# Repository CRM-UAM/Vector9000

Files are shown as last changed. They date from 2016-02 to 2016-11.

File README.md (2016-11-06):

Vector-9000, a fast line follower robot
===============

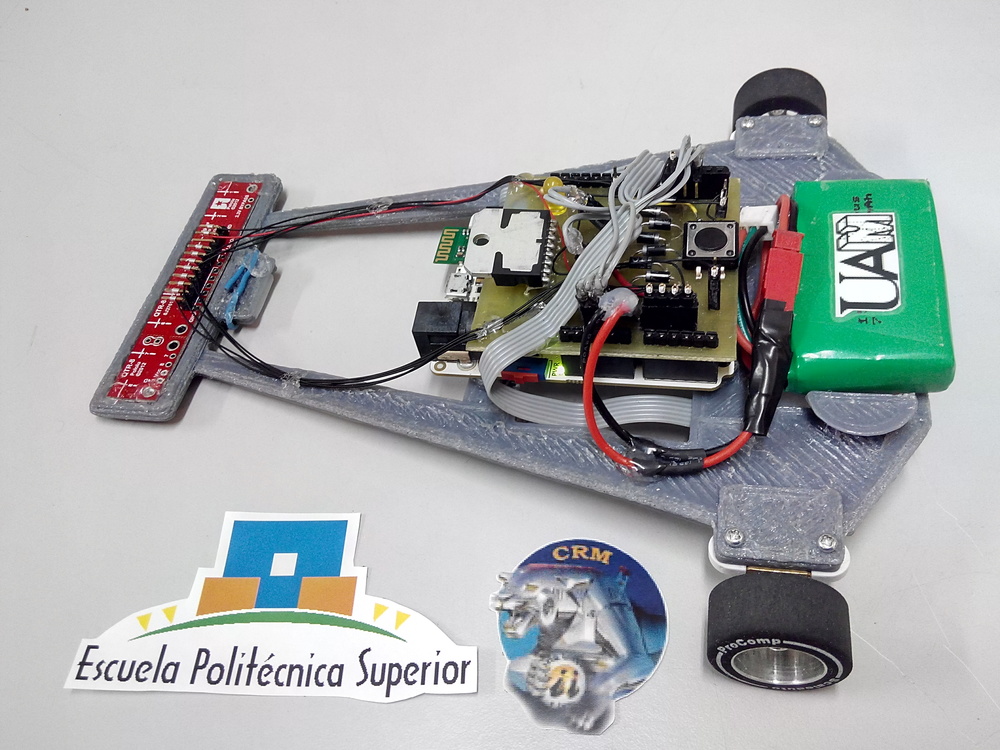
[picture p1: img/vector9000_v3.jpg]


Description
--------
By Carlosgs and Víctor Uceda.<br />
<br />
This robot was designed and built two weeks ahead the Cosmobot 2013 competition (http://www.roboticspot.com/cosmobot/).<br />

Video: <a href="http://www.youtube.com/watch?v=wgSMBDEtGO0" target="_blank" rel="nofollow">youtube.com/watch?v=wgSMBDEtGO0</a><br />

Tech specs:<br />

 - Arduino Leonardo with CRM Shield + MUX + lots of wire-wrapping<br />
 - Pololu QTR-8A (RC) and CNY-70 line sensor boards<br />
 - 7.4V Li-Po battery<br />
 - LDR sensor array (x4) as an experiment to determine the robot's orientation

Files
--------

 [ SoporteLDR.stl](3D_design/SoporteLDR.stl)  


 [ TercerApoyo.stl](3D_design/TercerApoyo.stl)  


 [ NuevaCover.stl](3D_design/NuevaCover.stl)  


 [ Chasis.stl](3D_design/Chasis.stl)  


 [ CubiertaPololu.stl](3D_design/CubiertaPololu.stl)  

 Original design as of 2013:
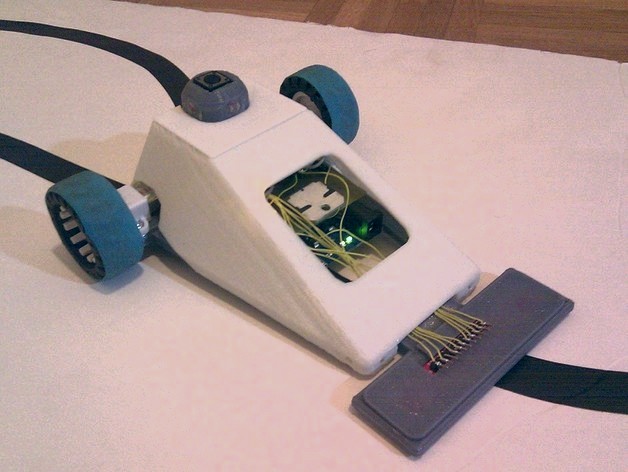
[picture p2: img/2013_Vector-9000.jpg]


License: CC-BY-SA 4.0 international


 [ TercerApoyo.scad](3D_design/TercerApoyo.scad)  


 [ LineSensorV2_new.scad](3D_design/LineSensorV2_new.scad)  


 [ CubiertaPololu.scad](3D_design/CubiertaPololu.scad)  


 [ CubiertaCarcasa.scad](3D_design/CubiertaCarcasa.scad)  


 [ Chasis.scad](3D_design/Chasis.scad)  


 [ CubiertaCarcasa.stl](3D_design/CubiertaCarcasa.stl)  


 [ SoporteLDR.scad](3D_design/SoporteLDR.scad)  

Pictures
--------
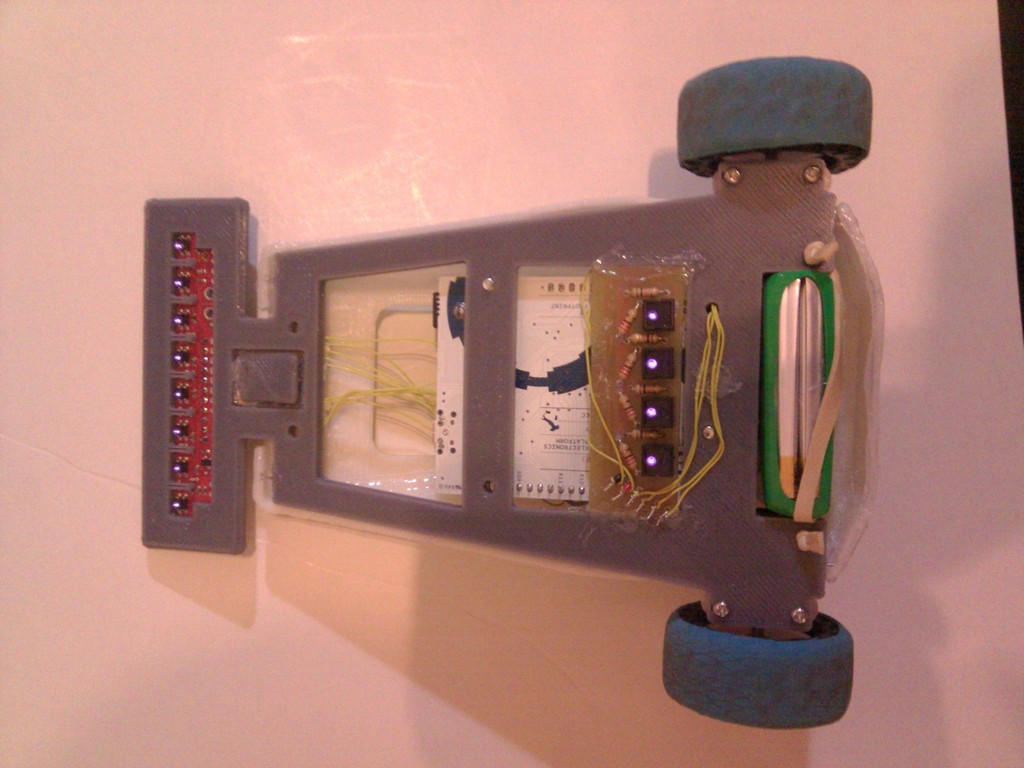
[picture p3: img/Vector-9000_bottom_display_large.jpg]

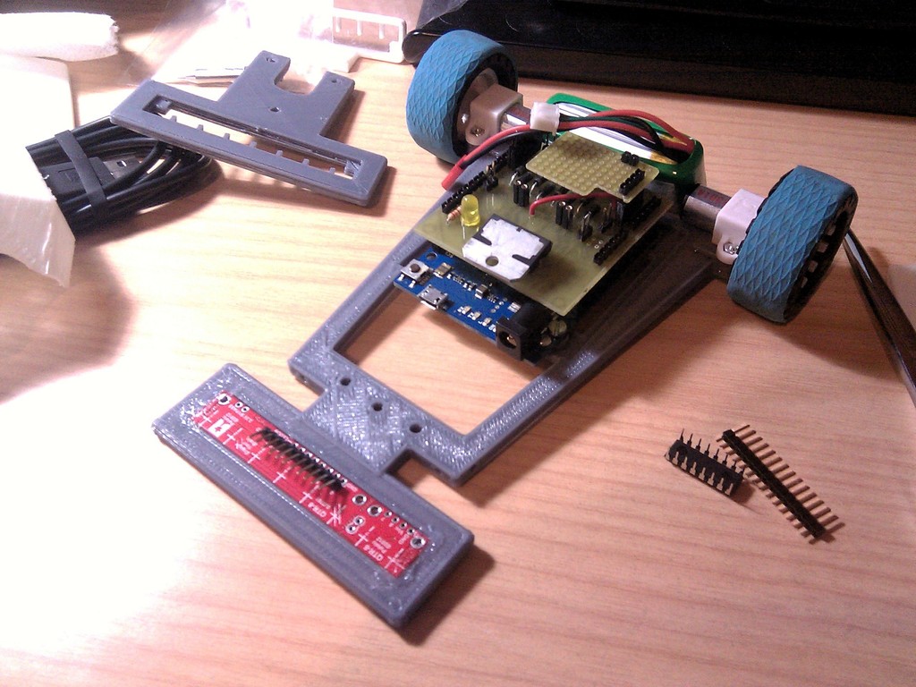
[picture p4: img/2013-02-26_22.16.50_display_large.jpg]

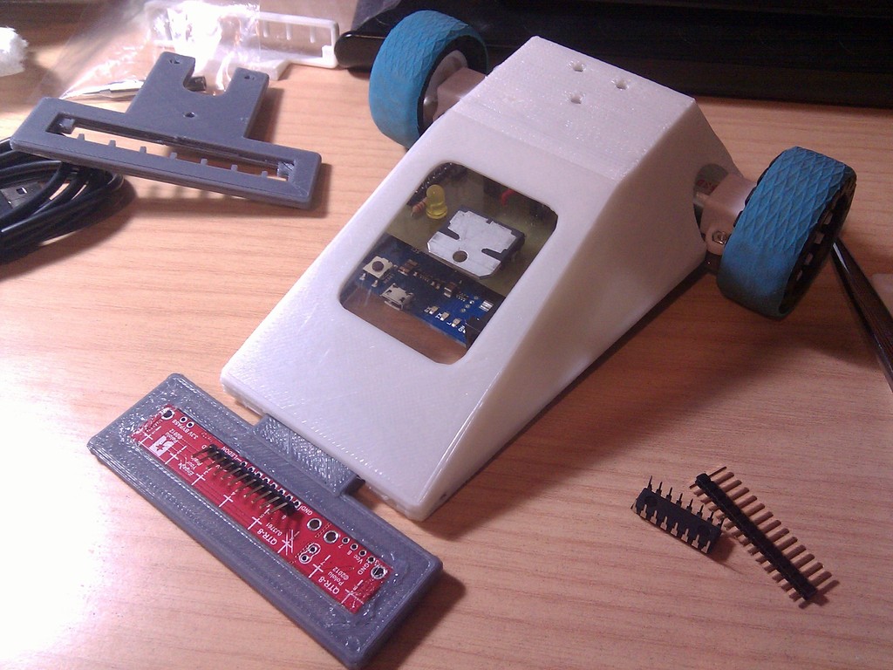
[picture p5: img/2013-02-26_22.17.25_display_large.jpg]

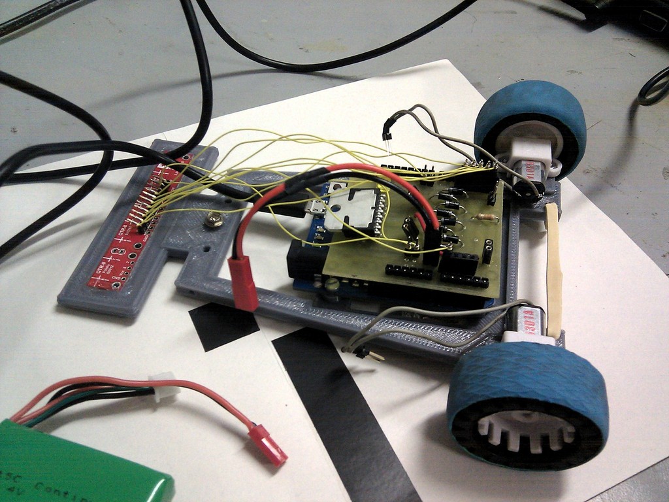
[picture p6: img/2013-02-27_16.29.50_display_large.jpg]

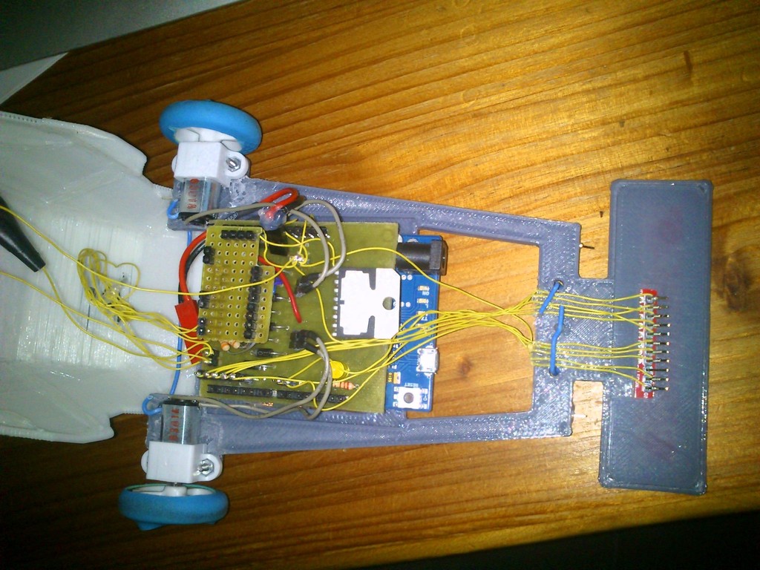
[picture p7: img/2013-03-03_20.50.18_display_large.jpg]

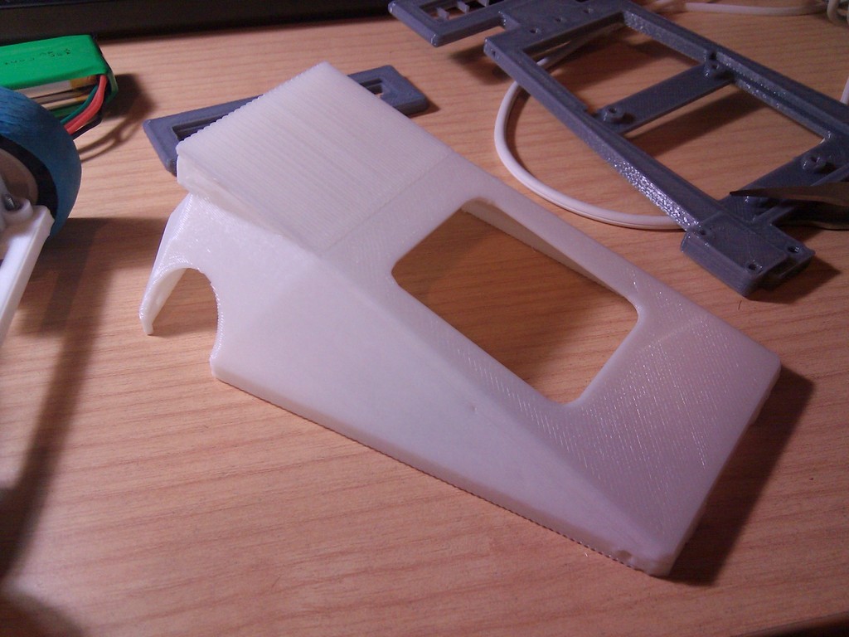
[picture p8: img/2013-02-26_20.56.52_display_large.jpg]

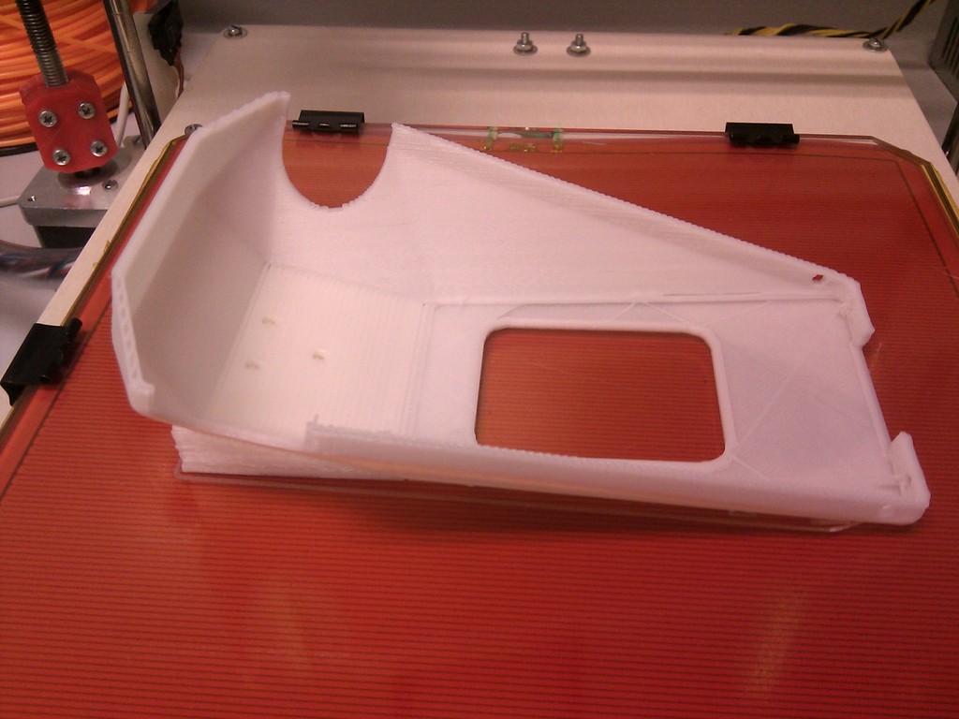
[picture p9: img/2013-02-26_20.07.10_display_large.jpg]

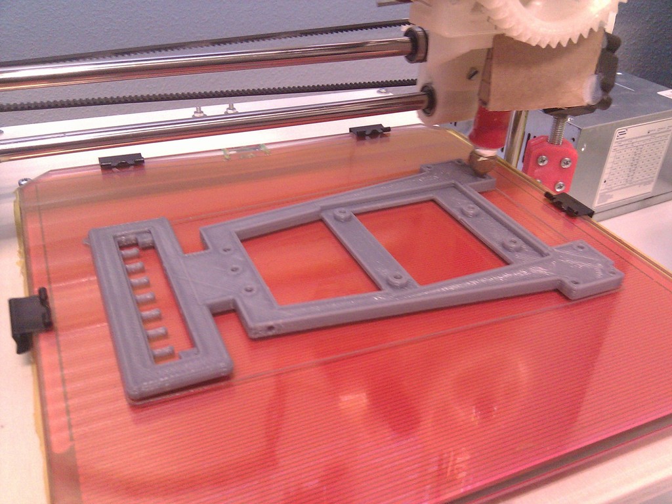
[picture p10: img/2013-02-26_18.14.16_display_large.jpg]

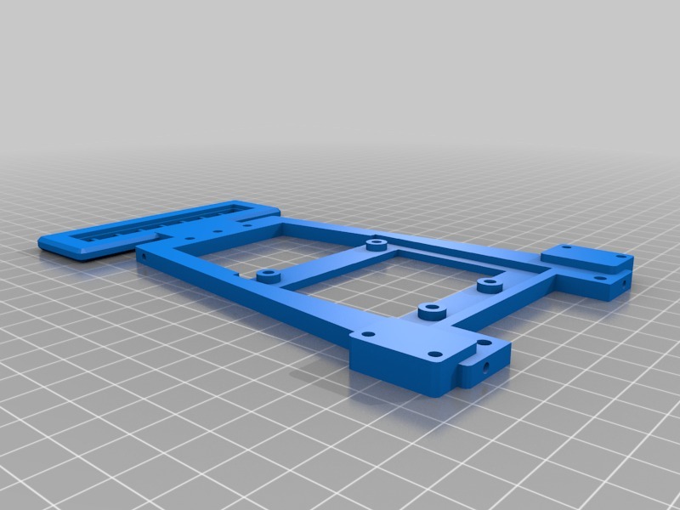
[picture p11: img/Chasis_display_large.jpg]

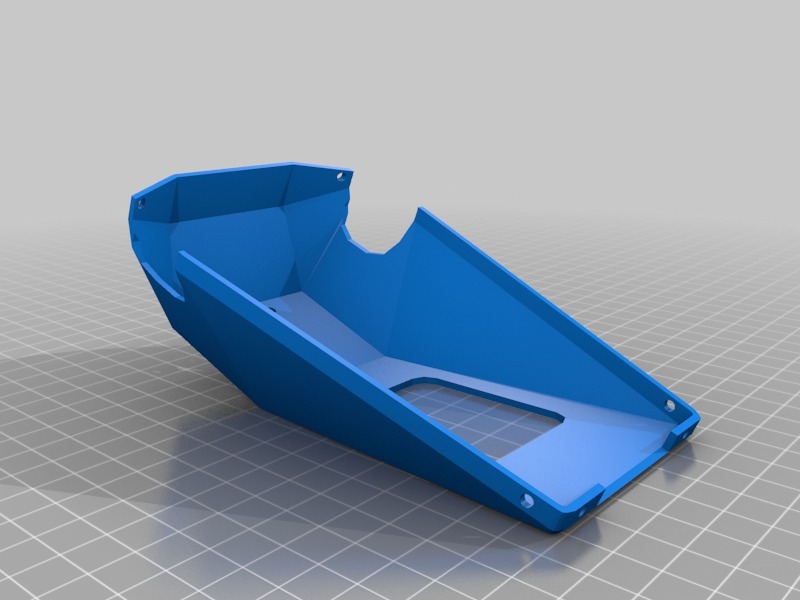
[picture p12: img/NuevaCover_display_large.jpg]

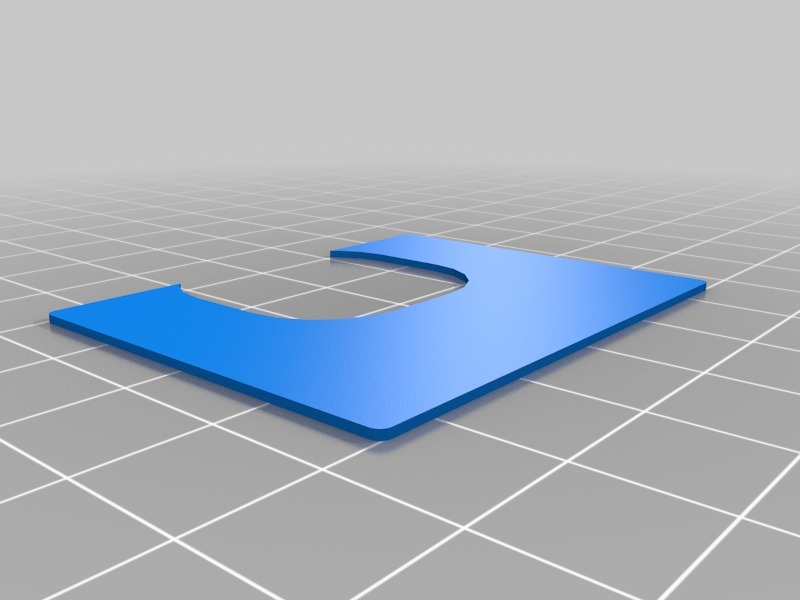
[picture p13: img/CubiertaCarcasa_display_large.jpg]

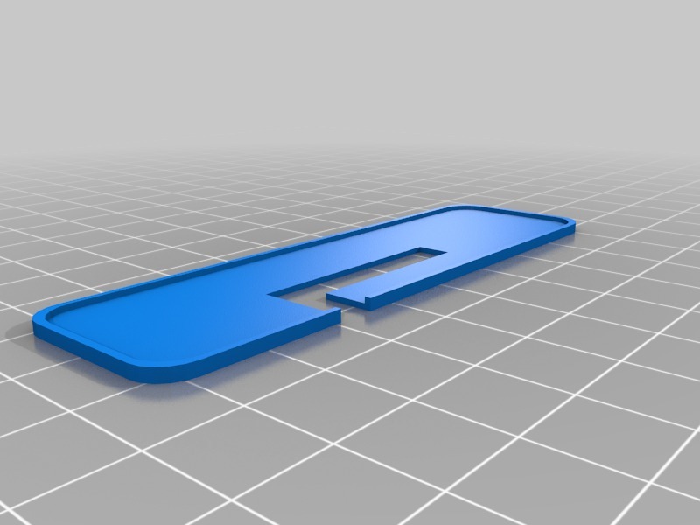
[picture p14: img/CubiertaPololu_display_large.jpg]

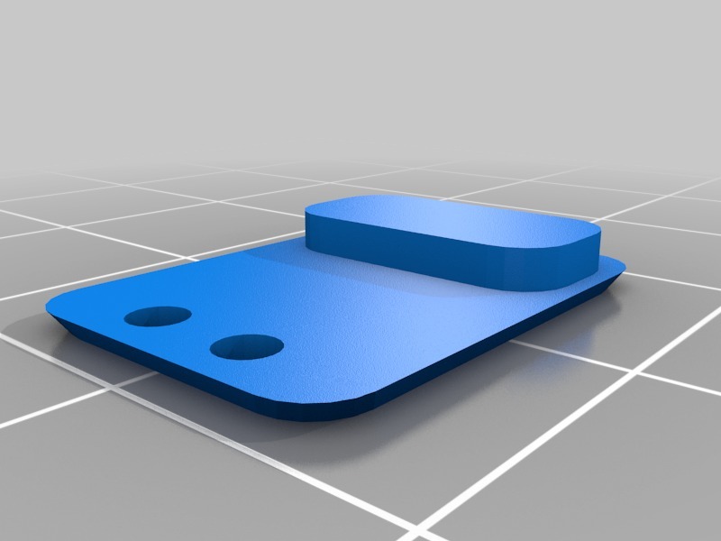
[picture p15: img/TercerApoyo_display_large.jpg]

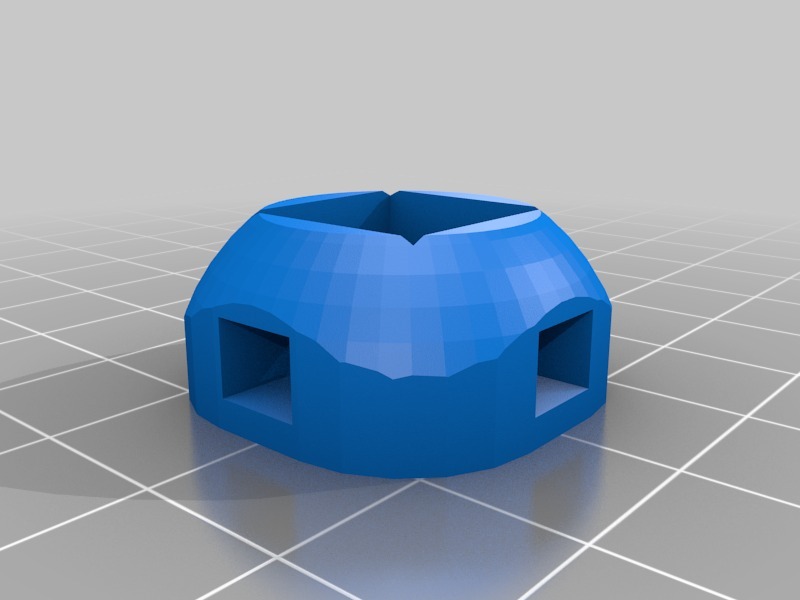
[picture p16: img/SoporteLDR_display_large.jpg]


Tags
--------
ARDUINO , CRM , PLASTIC_VALLEY , PRINTBOT , SHIELD , UAM  

License
--------
Vector-9000, a fast line follower robot by carlosgs is licensed under the Creative Commons - Attribution - Share Alike license.

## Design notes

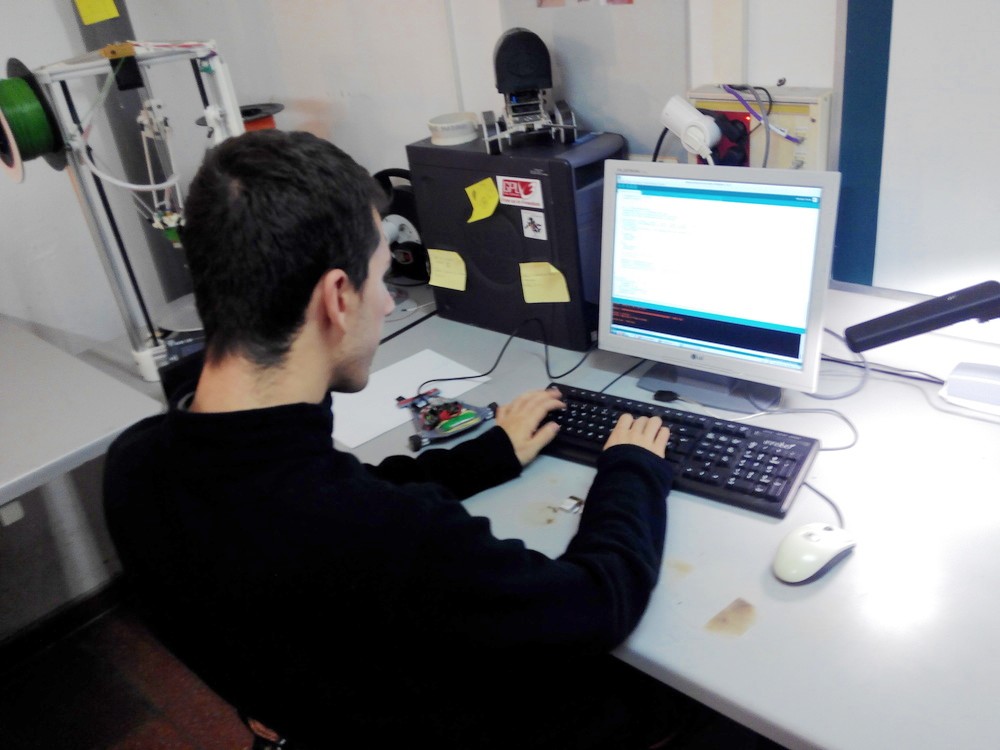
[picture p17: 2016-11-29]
img/2016-10-30_Victor_a_tope_Vector9000.jpg

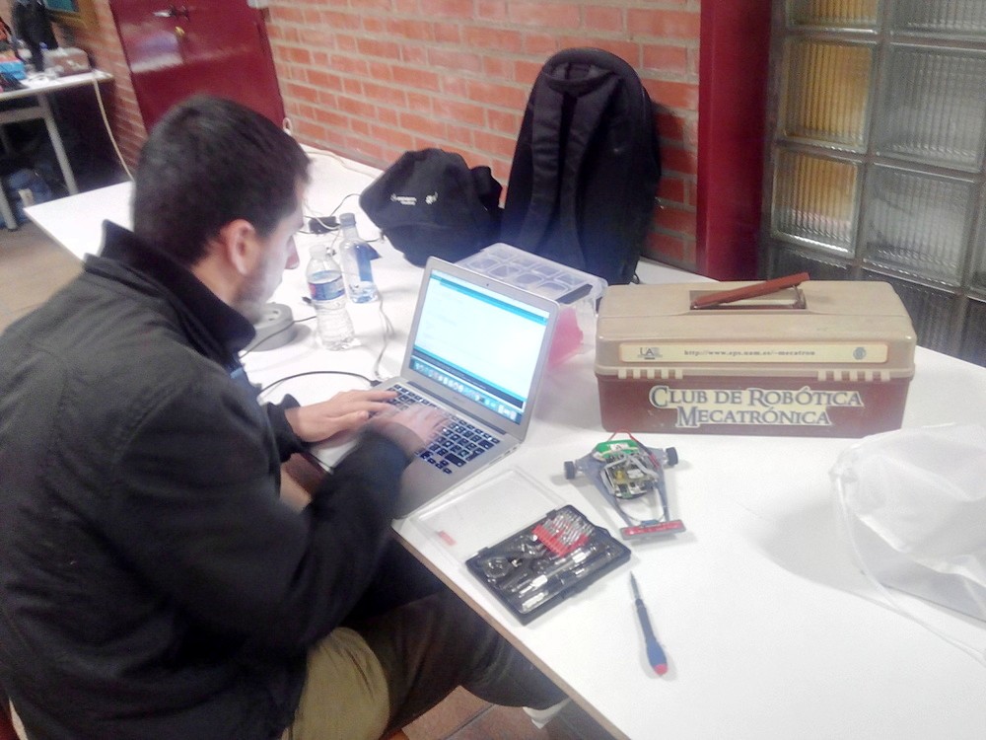
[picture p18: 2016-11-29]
img/2016-04-08 13.01.25.jpg

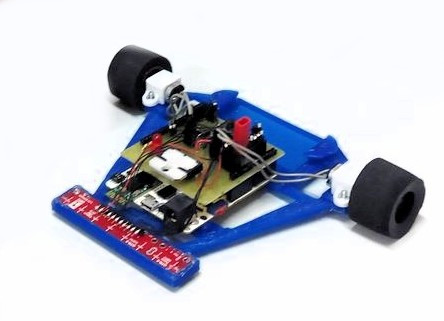
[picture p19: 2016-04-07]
img/miniVector_7apr2016_robolid.jpeg

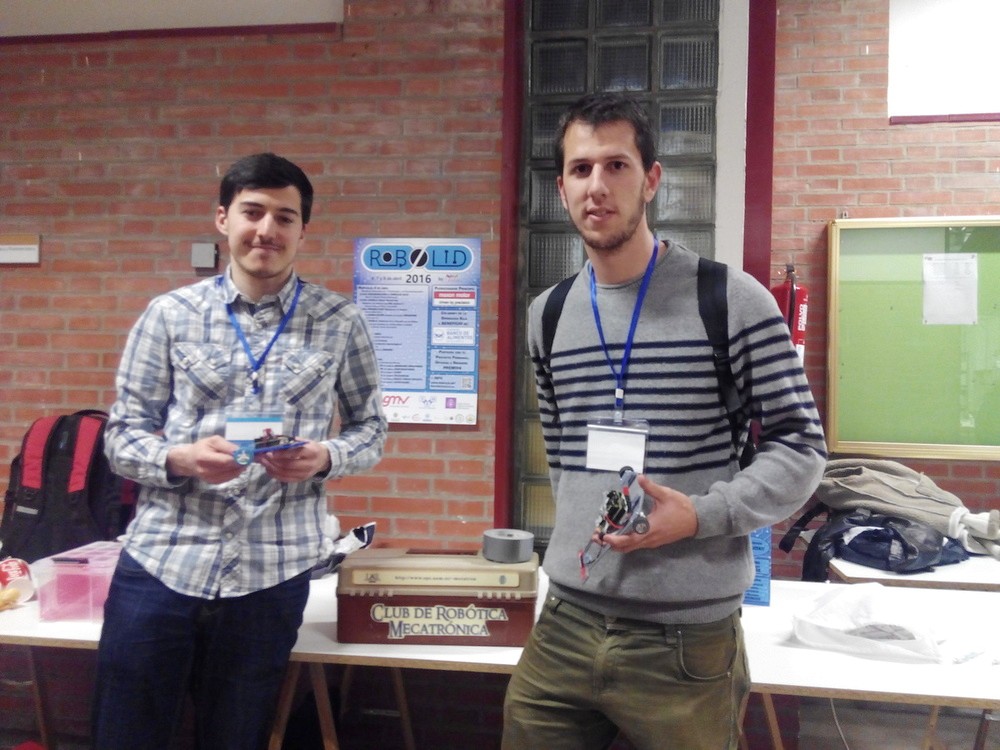
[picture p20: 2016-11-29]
img/2016-04-08 20.31.52.jpg

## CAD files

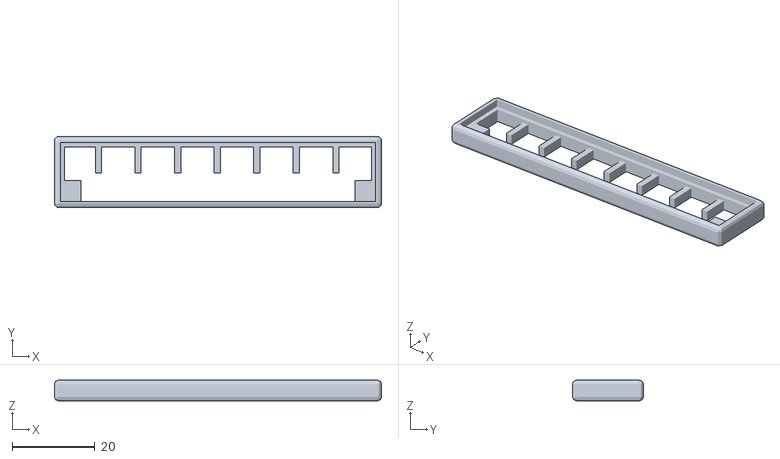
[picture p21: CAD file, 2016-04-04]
3D_design/LineSensorV2_new.stl
79.0 x 17.2 x 5.00

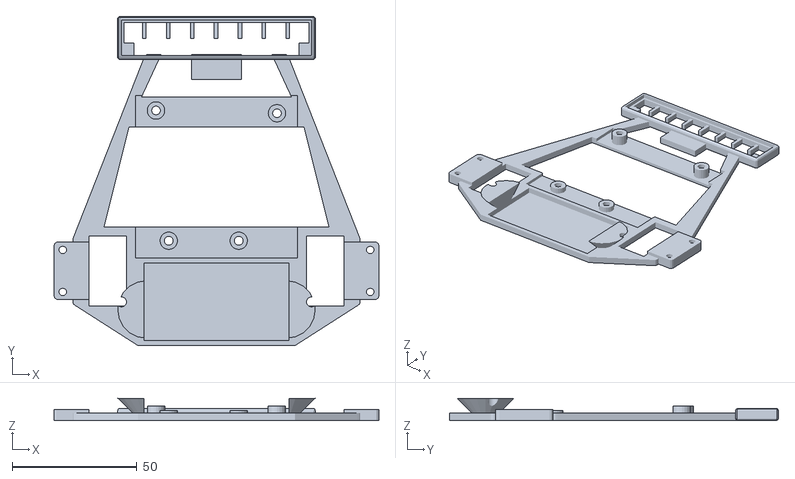
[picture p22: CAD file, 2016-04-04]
3D_design/STL/Chasis_v2_corto.stl
130.0 x 131.6 x 9.00

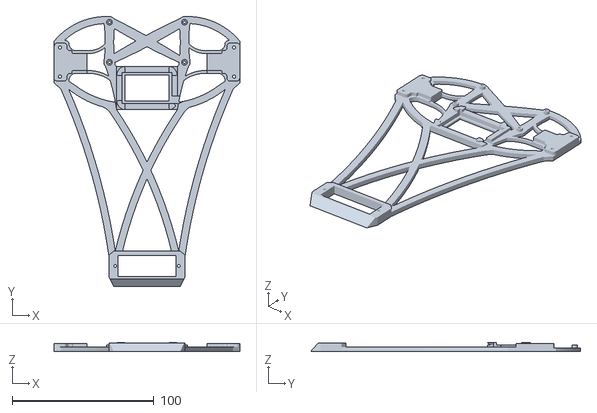
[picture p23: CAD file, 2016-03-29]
3D_design/base_velocistaEdu_fixed.stl
131.0 x 190.7 x 6.50

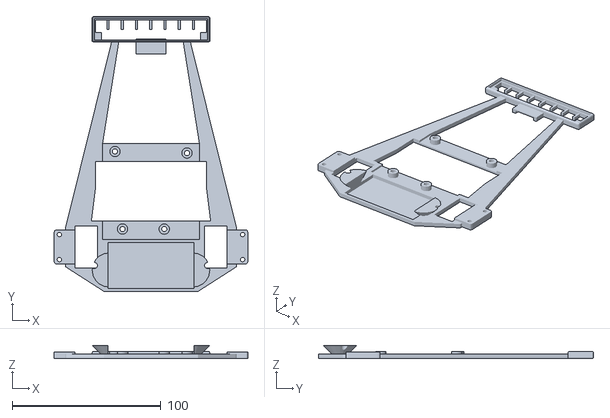
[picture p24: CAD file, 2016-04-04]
3D_design/STL/Chasis_v2.stl
130.0 x 184.6 x 9.00

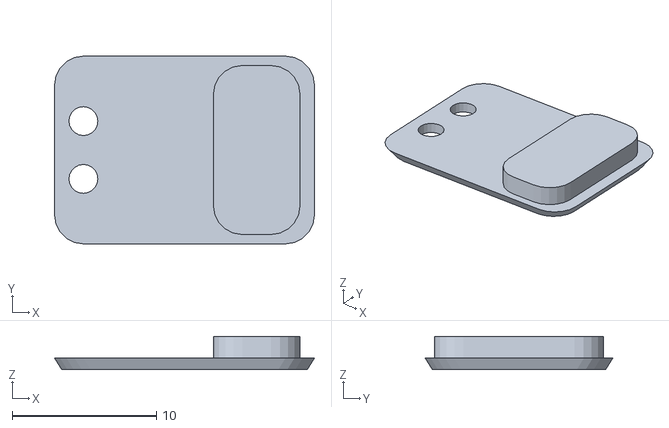
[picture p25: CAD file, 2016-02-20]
3D_design/STL/TercerApoyo.stl
18.0 x 13.0 x 2.30

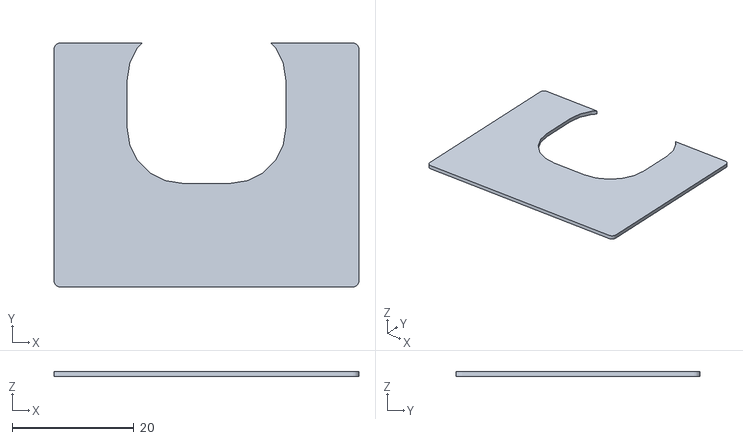
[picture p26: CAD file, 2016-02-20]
3D_design/STL/CubiertaCarcasa.stl
50.0 x 40.0 x 0.8

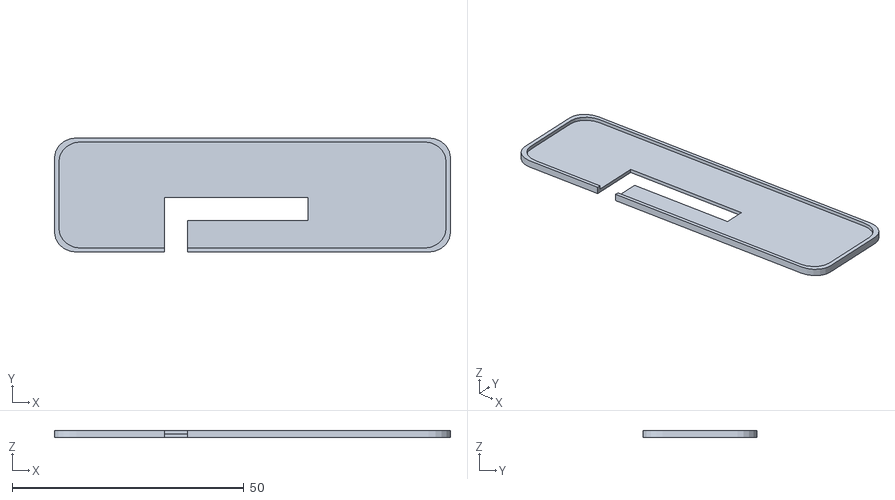
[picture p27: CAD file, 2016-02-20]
3D_design/STL/CubiertaPololu.stl
85.5 x 24.6 x 1.60

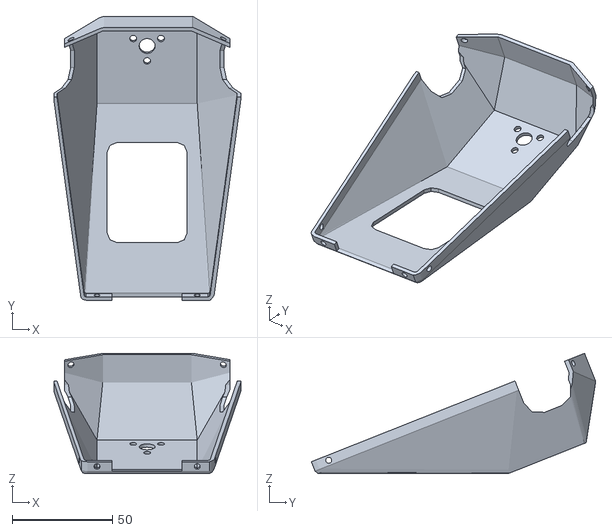
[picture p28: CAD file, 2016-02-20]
3D_design/STL/NuevaCover.stl
93.3 x 141.8 x 60.0

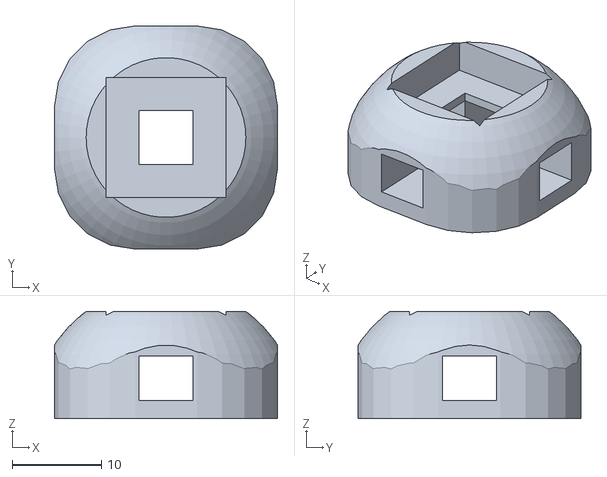
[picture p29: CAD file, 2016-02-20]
3D_design/STL/SoporteLDR.stl
25.0 x 25.0 x 12.0

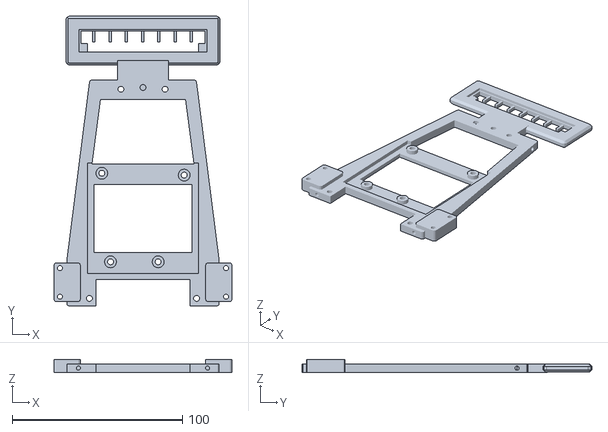
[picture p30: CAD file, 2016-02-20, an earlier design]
3D_design/STL/Chasis_v1.stl
104.7 x 170.4 x 7.50

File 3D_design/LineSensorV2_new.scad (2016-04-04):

// Vector-9000 - fast line follower robot (version 1.0)
// by Carlosgs (http://carlosgs.es) and Víctor Uceda
// CC-BY-SA license (http://creativecommons.org/licenses/by-sa/3.0/)
// Check http://www.thingiverse.com/thing:65012 for more information

// Original line sensor designed by bitswype (see http://www.thingiverse.com/thing:30516)


$fn = 50;

inches_to_mm = 25.4;

shell_thickness = 1.5;
sensor_width = 75.2+1;
sensor_depth = 13.2+1;
support_thickness = 1;
peg_square = 5;


finger_thickness = 1.5;
finger_offset = 8.73+0.5;
finger_center = 9.56;
finger_length = 6.32;

shell_height = 5;
support_height = 3.2;

finger_height = support_height-0.8;

// ----- sensor arm parameters
spacer_thickness = 10.7;
arm_thickness = 5;
connector_height = 24;  //34
connector_thickness = 4;
bolt_spacing = 4;
sensor_connector_depth = 10;
peg_diameter = 3.5;
arm_height = 7;  //17
arm_spacing = 12;
arm_hole_clearance = 0.5;
arm_width = 4;
arm_length = 50;
robot_extra_size = 6;
robot_thickness = 4;
screw_head_clearance = 4;
screw_center = 0.5*inches_to_mm;
screw_hole_diameter = 0.185*inches_to_mm;
arm_clearance = 4;


sensor_holder_length = 2*shell_thickness+sensor_width;
sensor_holder_width = 2*shell_thickness+sensor_depth;

support_h = shell_height;
support_w = 25*2;
support_l = 40;

restpoint_hole_depth = 2.5;

// for printing
translate([-sensor_holder_length/2,0,0])
  intersection() { // Create rounded border
    sensor_holder();
    roundedRect([sensor_holder_length,sensor_holder_width,shell_height],1);
  }

//sensor_arm();

//robot_arm_connector();

//arm_spacer();


// --------------------- construct the holder ---------------------------------

//sensor_holder();
//sensor_connector();
//
//color("orange") translate([shell_thickness+sensor_width/2-spacer_thickness/2,-sensor_connector_depth/2,arm_height]) rotate([90,0,-90]) sensor_arm();
//color("orange") translate([shell_thickness+sensor_width/2-spacer_thickness/2,-sensor_connector_depth/2,arm_height+arm_spacing]) rotate([90,0,-90]) sensor_arm();
//
//color("orange") translate([shell_thickness+sensor_width/2+spacer_thickness/2,-sensor_connector_depth/2,arm_height]) rotate([-90,0,-90]) sensor_arm();
//color("orange") translate([shell_thickness+sensor_width/2+spacer_thickness/2,-sensor_connector_depth/2,arm_height+arm_spacing]) rotate([-90,0,-90]) sensor_arm();
//
//color("green") translate([shell_thickness+sensor_width/2-spacer_thickness/2,-sensor_connector_depth/2-arm_length,arm_height]) rotate([0,90,0]) arm_spacer();
//color("green") translate([shell_thickness+sensor_width/2-spacer_thickness/2,-sensor_connector_depth/2-arm_length,arm_height+arm_spacing]) rotate([0,90,0]) arm_spacer();
//
//
//
//color("blue") translate([shell_thickness+sensor_width/2, -sensor_connector_depth/2-arm_length, arm_height]) rotate([-90,0,-90]) translate([-robot_extra_size-screw_center/2, -(robot_thickness+arm_width+arm_clearance+peg_diameter/2+arm_spacing), -(2*robot_thickness+2*screw_head_clearance+screw_center)/2]) union()
//{
//  robot_arm_connector();
//
//  translate([2*robot_extra_size+screw_center,0, 2*robot_thickness+2*screw_head_clearance+screw_center])rotate([0,180,0]) robot_arm_connector();
//}

// --------------------modules-------------------------------

module sensor_connector()
{
  difference()
  {
    // main connector body
    translate([shell_thickness+sensor_width/2-spacer_thickness/2,-sensor_connector_depth, 0]) cube([spacer_thickness,sensor_connector_depth,connector_height]);
    // left side pegs
    translate([shell_thickness+sensor_width/2-spacer_thickness/2-1,-sensor_connector_depth/2,arm_height]) rotate([0,90,0]) cylinder(r=peg_diameter/2, h=spacer_thickness+2);
    translate([shell_thickness+sensor_width/2-spacer_thickness/2-1,-sensor_connector_depth/2,arm_height+arm_spacing]) rotate([0,90,0]) cylinder(r=peg_diameter/2, h=spacer_thickness+2);
  }
}

module arm_spacer()
{
  linear_extrude(height=spacer_thickness) difference()
  {
    circle(r= peg_diameter/2+arm_hole_clearance/2+arm_width/2);
    circle(r= peg_diameter/2+arm_hole_clearance/2);
  }
}

module robot_arm_connector()
{
  difference()
  {
    union()
    {
      cube([2*robot_extra_size+screw_center, robot_thickness, robot_thickness+2*screw_head_clearance]);
      cube([2*robot_extra_size+screw_center, robot_thickness+arm_width+arm_clearance+peg_diameter+arm_spacing+peg_diameter, robot_thickness]);
    }
    
    translate([robot_extra_size, robot_thickness/2, robot_thickness+screw_head_clearance]) rotate([90,0,0]) cylinder(r=screw_hole_diameter/2, h=robot_thickness+2, center=true);
    translate([robot_extra_size+screw_center, robot_thickness/2, robot_thickness+screw_head_clearance]) rotate([90,0,0]) cylinder(r=screw_hole_diameter/2, h=robot_thickness+2, center=true);
    
      // pegs
    translate([robot_extra_size+screw_center/2, robot_thickness+arm_width+arm_clearance+peg_diameter/2, -1]) cylinder(r=peg_diameter/2, h=robot_thickness+2);
    translate([robot_extra_size+screw_center/2, robot_thickness+arm_width+arm_clearance+peg_diameter/2+arm_spacing, -1]) cylinder(r=peg_diameter/2, h=robot_thickness+2);
  }
  
  
}

module sensor_arm()
{
  linear_extrude(height = arm_thickness) difference()
  {
    union()
    {
      translate([0,-arm_width/2]) square([arm_length, arm_width]);
      circle(r= peg_diameter/2+arm_hole_clearance/2+arm_width/2);
      translate([arm_length,0,0]) circle(r= peg_diameter/2+arm_hole_clearance/2+arm_width/2);    
    }
    
    circle(r= peg_diameter/2+arm_hole_clearance/2);
    translate([arm_length,0,0]) circle(r= peg_diameter/2+arm_hole_clearance/2);
  }
}

module sensor_holder()
{
  union()
  {
    // A
    linear_extrude(height=shell_height)
    difference()
    {
      //roundedRect([2*shell_thickness+sensor_width,2*shell_thickness+sensor_depth,shell_height],2);
      square([2*shell_thickness+sensor_width,2*shell_thickness+sensor_depth]);
      translate([shell_thickness, shell_thickness]) square([sensor_width, sensor_depth]);
      //translate([shell_thickness, shell_thickness, -1]) cube([sensor_width, sensor_depth, shell_height*2]);
    }

    // B
    linear_extrude(height=support_height) union()
    {
      translate([shell_thickness, shell_thickness]) square([support_thickness, sensor_depth]);
      translate([shell_thickness+sensor_width-support_thickness, shell_thickness]) square([support_thickness, sensor_depth]);
      translate([shell_thickness,shell_thickness+sensor_depth-support_thickness]) square([sensor_width, support_thickness]);
    }

    // C
    linear_extrude(height=support_height) union()
    {
      translate([shell_thickness,shell_thickness]) square([peg_square, peg_square]);
      translate([shell_thickness+sensor_width-peg_square,shell_thickness]) square([peg_square, peg_square]);
    }

    // D
    //translatecircle(r=peg_diameter/2);

    // fingers
    linear_extrude(height = finger_height) for(i = [0:6])
    {
      translate([shell_thickness-finger_thickness/2+finger_offset+i*finger_center,shell_thickness+sensor_depth-finger_length-support_thickness]) square([finger_thickness, finger_length]);
    }
  }
}




// http://www.thingiverse.com/thing:9347
module roundedRect(size, radius)
{
$fn=8;
x = size[0]-radius*2;
y = size[1]-radius*2;
z = size[2]-radius*2;

translate([radius,radius,radius])
minkowski()
{
cube(size=[x,y,z]);
rotate([70,0,0]) sphere(r=radius);
}
}

// http://www.thingiverse.com/thing:9347
module roundedRect2D(size, radius)
{
$fn=8;
x = size[0]-radius*2;
y = size[1]-radius*2;
z = size[2];

minkowski()
{
cube(size=[x,y,z],center=true);
cylinder(r=radius,h=0.00001);
}
}

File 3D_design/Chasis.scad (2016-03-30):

// Vector-9000 - fast line follower robot (version 1.0)
// by Carlosgs (http://carlosgs.es) and Víctor Uceda
// CC-BY-SA license (http://creativecommons.org/licenses/by-sa/3.0/)
// Check http://www.thingiverse.com/thing:65012 for more information

#translate([165,55,30])rotate([0,0,180])import("base_velocistaEdu_fixed.stl");

longitudPlaca=140;
anchoPlaca=longitudPlaca/1.25;
grosorPlaca=3;
separacionTornilloMotores=16.8;
offsetRueda=5;
diametroRueda=42;
drill_M3=3;

resolucion_taladros=20;

taladro_arduino=3.5;

diametroBolaLoca=28.7;
alturaBolaLoca=26;

corner_radius = 3/2;

margen_motores = 5-corner_radius;
margenY_motores = 5;

margenPCBsensores=1;

grosorPCB=1.56;
alturaSensorCNY70=5.9;
grosorPegamento=1;

anchoSoporteMotores=15;

longitudBateria = 58;

ancho_placaCNY70 = 50;

separacion_tornillos_frontal = 26;

longitud_zona_motores = anchoSoporteMotores+2*margenY_motores;

// From MiniSkyBot v2
module arduinoDrills(taladro_arduino=3.5, center=true, h = grosorPlaca+10) {
    translate([-51/2,48.4/2,0]) {
	//-- Arduino drill 1 (top-left)
    cylinder(r=taladro_arduino/2, h=h,center=center, $fn=resolucion_taladros);

    //-- Arduino drill 2 (bottom-left)
    translate([-1.1,-48.4,0])
    cylinder(r=taladro_arduino/2, h=h,center=center, $fn=resolucion_taladros);

    //-- Arduino drill 3 (top-right)
    translate([51,-15.3,0])
    cylinder(r=taladro_arduino/2, h=h,center=center, $fn=resolucion_taladros);

    //-- Arduino drill 3 (top-right)
    translate([51,-15.3-28,0])
    cylinder(r=taladro_arduino/2, h=h,center=center, $fn=resolucion_taladros);
	}
}

module placaBaseSinBola(nomotors=0) {
	minkowski() {
   union() {
	  hull() {
        translate([50/2,-16,0])
           cube([anchoPlaca-50,longitud_zona_motores,grosorPlaca/2]);
		cube([anchoPlaca,longitud_zona_motores,grosorPlaca/2]);
		translate([anchoPlaca/2,longitudPlaca-32,grosorPlaca/4])
			//cylinder(r=anchoPlaca/3, h=grosorPlaca, $fn=150);
         cube([ancho_placaCNY70,longitudPlaca-anchoPlaca/2,grosorPlaca/2],center=true);
	  }
     if(nomotors) {//hueco para la batería en la carcasa
       translate([anchoPlaca/4,-10,0])
         cube([anchoPlaca/2,longitud_zona_motores,grosorPlaca/2+10]);
     }
     if(nomotors==0) {
       translate([anchoPlaca/2,longitud_zona_motores/2,grosorPlaca/2]) {
         difference() {
           cube([anchoPlaca+15,20,grosorPlaca],center=true);
           translate([0,0,grosorPlaca/4]) cube([anchoPlaca-10,20,grosorPlaca/2],center=true);
         }
       }
     }
   }
   cylinder(r=corner_radius, h=grosorPlaca/2, $fn=10);
   }
   soportesBateria();
}

module placaBase() {
	difference() {
		placaBaseSinBola();

		//Hueco en chasis
			translate([anchoPlaca/2,0,2.5+0.5])
				cube([longitudBateria,31,5],center=true);
			translate([anchoPlaca/2,longitud_zona_motores+25,-5])
				cube([anchoPlaca/1.5,40,100],center=true);
            translate([anchoPlaca/2,0,-5])
                hull(){
                    translate([0,longitud_zona_motores+5,-5])
                        cube([ancho_placaCNY70*1.6,0.0001,100], center=true);
                    translate([0,longitud_zona_motores+45,-5])
                        cube([ancho_placaCNY70+20,0.0001,100], center=true);
                }
hull(){
			translate([anchoPlaca/2-ancho_placaCNY70*1.3/2,longitud_zona_motores+57,-5])
				cube([ancho_placaCNY70*1.3,0.0001,100]);
			translate([anchoPlaca/2-ancho_placaCNY70/3-10/2,longitud_zona_motores+125,-5])
				cube([ancho_placaCNY70/1.5+10,0.0001,100]);
}
	}
}

module taladrosMotores(margenX,margenY) {
	//Motor derecho
margenX=-5.5;
margenY=4;
	translate([margenX,margenY,-5])
			cylinder(r=drill_M3/2, h=100, $fn=resolucion_taladros);
	translate([margenX,margenY+separacionTornilloMotores,-5])
			cylinder(r=drill_M3/2, h=100, $fn=resolucion_taladros);

	//Motor izquierdo
	translate([anchoPlaca-margenX,margenY,-5])
			cylinder(r=drill_M3/2, h=100, $fn=resolucion_taladros);
	translate([anchoPlaca-margenX,margenY+separacionTornilloMotores,-5])
			cylinder(r=drill_M3/2, h=100, $fn=resolucion_taladros);
}

module taladrosSoporteSensores() {
  translate([anchoPlaca/2,longitudPlaca-4,0]) {
    translate([-separacion_tornillos_frontal/2,0,0])
      cylinder(r=taladro_arduino/2, h=grosorPlaca+10,center=true, $fn=resolucion_taladros);
    translate([separacion_tornillos_frontal/2,0,0])
      cylinder(r=taladro_arduino/2, h=grosorPlaca+10,center=true, $fn=resolucion_taladros);
  }
}

module taladrosBateria() {
  translate([anchoPlaca/2,-3,0]) {
    translate([-longitudBateria/2-4,0,0])
      cylinder(r=5/2, h=grosorPlaca+10,center=true, $fn=resolucion_taladros);
    translate([longitudBateria/2+4,0,0])
      cylinder(r=5/2, h=grosorPlaca+10,center=true, $fn=resolucion_taladros);
  }
}

module bateria(){
    translate([anchoPlaca/2,0,15/2+0.5+1])
    rotate([90,0,0])
    color("green") cube([58,15,30],center=true);
}

module soportesBateria() {
  //bateria();
  difference() {
  translate([anchoPlaca/2,-3,0]) {
    translate([-longitudBateria/2+1,0,0])
      cylinder(r1=5/2, r2=23/2, h=grosorPlaca+6, $fn=resolucion_taladros);
    translate([longitudBateria/2-1,0,0])
      cylinder(r1=5/2, r2=23/2, h=grosorPlaca+6, $fn=resolucion_taladros);
  }
  bateria();
  }
}

module taladrosCarcasa(diam=3) {
  translate([anchoPlaca/2,0,0]) {
    // Zona trasera
    translate([-38,-10,grosorPlaca/2])
      rotate([90,0,0])
        cylinder(r=diam/2, h=grosorPlaca*2+20,center=true, $fn=resolucion_taladros);
    translate([38,-10,grosorPlaca/2])
      rotate([90,0,0])
        cylinder(r=diam/2, h=grosorPlaca*2+20,center=true, $fn=resolucion_taladros);

    // Zona frontal
    translate([-25,longitudPlaca,grosorPlaca/2])
      rotate([90,0,0])
        cylinder(r=diam/2, h=grosorPlaca*2,center=true, $fn=resolucion_taladros);
    translate([25,longitudPlaca,grosorPlaca/2])
      rotate([90,0,0])
        cylinder(r=diam/2, h=grosorPlaca*2,center=true, $fn=resolucion_taladros);

    // Zona lateral-frontal
    translate([-ancho_placaCNY70/2,longitudPlaca-5,grosorPlaca/2])
      rotate([0,90,0])
        cylinder(r=diam/2, h=grosorPlaca*2,center=true, $fn=resolucion_taladros);
    translate([ancho_placaCNY70/2,longitudPlaca-5,grosorPlaca/2])
      rotate([0,-90,0])
        cylinder(r=diam/2, h=grosorPlaca*2,center=true, $fn=resolucion_taladros);
  }
}

module CRM_BOT_chassis_placa() {
	difference() {
		placaBase();
		translate([anchoPlaca/2,50,0])
			rotate([0,0,270]) {
				arduinoDrills();
               translate([0,0,grosorPlaca])
                 cube([65,65,grosorPlaca],center=true);
         }
		taladrosMotores(margen_motores, margenY_motores);
      //taladrosSoporteSensores();
      //taladrosBateria();
      //taladrosCarcasa(2.5);
	}
}

module CRM_BOT_chassis() {
	union() {
		CRM_BOT_chassis_placa();
		translate([anchoPlaca/2,50,0])
			rotate([0,0,270]) {
           difference() {
             arduinoDrills(7,center=false,h=5);
             arduinoDrills();
           }
         }
	}
}

module cover_solid() {
  hull() {
    placaBaseSinBola(nomotors=1);
    translate([anchoPlaca/2,longitudPlaca/3-40/2,30+10])
        cube([50,40,0.0001],center=true);
  }
}

module cover_solid_motors() {
  hull() {
    	minkowski() {
	  cube([anchoPlaca,longitud_zona_motores,grosorPlaca/2]);
     cylinder(r=corner_radius, h=grosorPlaca/2, $fn=10);
   }
    translate([anchoPlaca/2,longitudPlaca/3-40/2,30])
        cube([50,40,0.0001],center=true);
  }
}

module cover(thickness = 2) {
//rotate([180+21.4,0,0])
	difference() {
	  minkowski() {
	    cover_solid();
	    sphere(r=thickness, $fn=5);
	    //cube([1,1,1],center=true);
	  }
	  translate([0,0,-0.05]) cover_solid();
	  translate([0,0,-10]) cube([1000,1000,20],center=true);
     taladrosCarcasa(diam=3);
	}
}

module cover_front() {
	//translate([0,0,grosorPlaca])
	difference() {
	cover();
		difference() {
		  minkowski() {
		    cover_solid_motors();
		    sphere(r=2, $fn=5);
		    //cube([1,1,1],center=true);
		  }
		  translate([0,0,-0.05]) cover_solid_motors();
		  translate([0,0,-10]) cube([1000,1000,20],center=true);
		}
	}
}

module cover_back() {
	difference() {
		difference() {
		  minkowski() {
		    cover_solid_motors();
		    sphere(r=2, $fn=5);
		    //cube([1,1,1],center=true);
		  }
		  translate([0,0,-0.05]) cover_solid_motors();
		  translate([0,0,-10]) cube([1000,1000,20],center=true);
		}
	cover();
	}
}
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

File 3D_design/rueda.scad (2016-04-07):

// CRMaze robot
// By Víctor Uceda & Carlos García
//   Club de Robótica-Mecatrónica,
//   Universidad Autónoma de Madrid
//   http://crm-uam.github.io
//
// Derived from:
//   Pololu motor STL by Andrew Taylor ( https://grabcad.com/library/pololu-micro-motor-1-250-reduction-1 )
//   Sharp IR sensor STL by Mojtaba ( https://grabcad.com/library/ir-sensor )


// Increase the resolution of default shapes
$fa = 5; // Minimum angle for fragments [degrees]
$fs = 0.5; // Minimum fragment size [mm]


largo=75;
ancho=70;
grosor=1.6;

tolerancia=0.225;

module rueda(ra=25/2,ancho=17){
    #translate([-6,-5,1]) import("libs/motor.stl");

    color("gray") union() {
        translate([0,0,19])
            difference() {
                difference() {
                    hull() {
                        cylinder(r=ra,h=ancho-2);
                        translate([0,0,ancho-2.01]) cylinder(r=ra-1,h=2);
                    }
                    difference() {
                        translate([0,0,-0.1]) cylinder(r=ra-1.5,h=15);
                        translate([0,0,9]) cylinder(r=6/2,h=15);
                    }
                }
                difference() {
                    cylinder(r=3.3/2+tolerancia,h=ancho+1);
                    translate([-10,1.2+tolerancia,0]) cube([20,20,ancho+2]);
                }
                translate([0,0,ancho+1]) sphere(r=5/2);
                //cube([100,100,100]);
            }
    }
   
}

rotate([180,0,0]) rueda();

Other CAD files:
3D_design/Chasis_v2_corto.scad
3D_design/CubiertaCarcasa.scad
3D_design/CubiertaPololu.scad
3D_design/SoporteLDR.scad
3D_design/TercerApoyo.scad

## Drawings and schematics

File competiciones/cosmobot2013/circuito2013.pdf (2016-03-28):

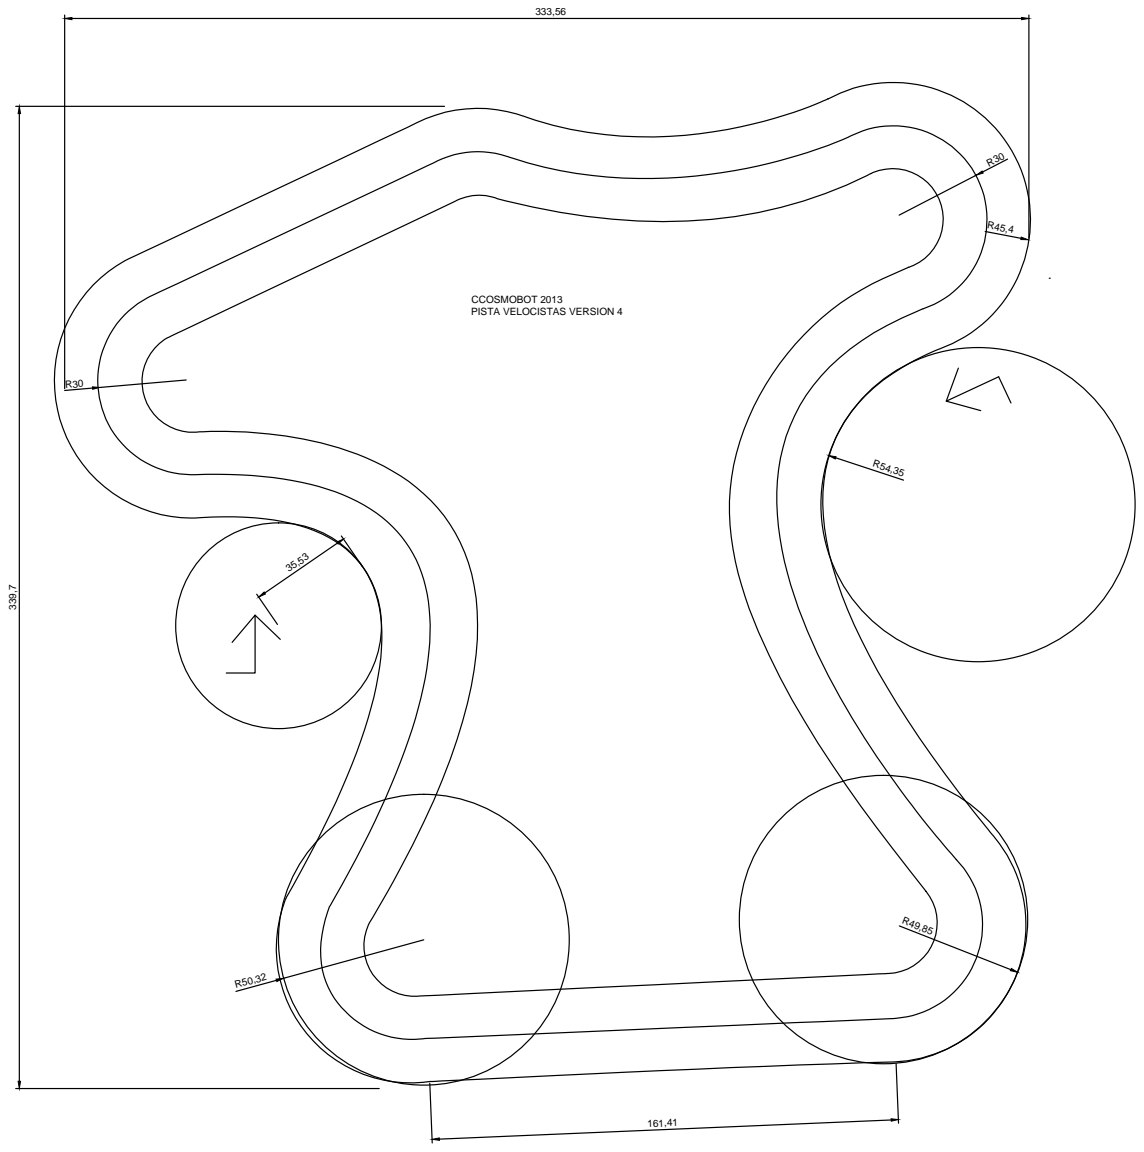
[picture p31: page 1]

CCOSMOBOT 2013
PISTA VELOCISTAS VERSION 4

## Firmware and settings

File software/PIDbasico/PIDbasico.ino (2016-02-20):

#include <EEPROM.h>
#include <QTRSensors.h>
#include <Arduino.h>
#include <math.h>



#define KD 2200
#define KP 0.06
#define VEL_BASE 50
#define VEL_RECTA 50
#define VEL_FRENO 50

unsigned long initialTime,lastLogTime;

#define LED 13       // Pin para el LED
#define M_INPUT_1 11  // Pines para el driver de motores L298
#define M_INPUT_2 9
#define M_INPUT_3 10
#define M_INPUT_4 12
#define M_ENABLE_A 6
#define M_ENABLE_B 5


#define LIM_MOTORES 200

#define NUM_CNY70 4

#define QTR_0 8
#define QTR_1 4
#define QTR_2 3
#define QTR_3 2
#define QTR_4 A1
#define QTR_5 7
#define QTR_6 A2
#define QTR_7 A0
#define NUM_SENSORS 8
#define LONG_RECTA 500000 //1 seg
#define TIMEOUT 2000  // waits for 2500 us for sensor outputs to go low
#define /*EMITTER_PIN 13 */EMITTER_PIN QTR_NO_EMITTER_PIN    // Controlar el emiso IR con el pin 13 como salida (Cuidado LED) o siempre encendido QTR_NO_EMITTER_PIN

#define INTER_ERR_D 10000 //Intervalo de tiempo para generar la parte derivativa del errorr (en uSeg) [a 2m/s en 10000us avanza 2cm]

#define PULSADOR A5   //Pin para el pulsador


#define MUX_S0 A1
#define MUX_S1 A2
#define MUX_S2 A3
#define MUX_Z A4

// ID relativo al MUX
#define IR_4 1
#define IR_3 2
#define IR_2 3
#define IR_1 0
#define LDR_1 4
#define LDR_2 5
#define LDR_2 6
#define LDR_2 7

#define RUIDO_LDR 100

#define LDR_FRONT 4
#define LDR_RIGHT 5
#define LDR_BACK 6
#define LDR_LEFT 7

/*^^^^^^^^^^^^^^^^^^^^^^^^^ PROTOTIPOS .H ^^^^^^^^^^^^^^^^^^^^^^^^^^^*/
/**** MOTORES ****/
void inicia_pines_driver_motores();
/*Funciones para el control de los motores
 Toman un parametro que va de -255 a 255 que indica la velocidad y direccion de rotacion*/
void motor_izq(int velocidad);
void motor_der(int velocidad);


/*** SENSORES QTR-8RC ***/

void calibraIR(int seg);
/*Ejecutar solo una vez [ en setup() ] imprime por el puerto serie*/

void prueba_sensoreIR(unsigned int *sensorValues);
/*Realiza lectura de los sensores y de linea imprime por el puerto serie*/


int getErrorPD(unsigned int *sensorValues,double kp, double kd);
/*Devuelve el error que tenemos que aplicar a los motores directamente, la salida del control PD:
  La parte derivativa se ejecuta solo si ha pasado INTER_ERR_D uSeg desde alguna llamada anterior
  retorno: [-3500*kp-7000*kd , 3500*kp+7000*kd]
 */
/*^^^^^^^^^^^^^^^^^^^^^^^^^^^^^^^^^^^^^^^^^^^^^^^^^^*/
/**********VARIABLES GLOBALES ***********************/
int minIRSensor[4];
int maxIRSensor[4];
int minLDRSensor[4];
int maxLDRSensor[4];




unsigned int sensorValues[NUM_SENSORS];
int errArray[200];
int i=-1;
int parpadeoled=0;
unsigned long rectaTime=0;

/*^^^^^^^^^^^^^^^^^^^^^^^^^ FUNCIONES BASICAS .c ^^^^^^^^^^^^^^^^^^^^^^^^^^^*/
/*********  MOTORES  *********/
void inicia_pines_driver_motores() {
  // Inicia los pines como salidas
  pinMode(M_INPUT_1, OUTPUT);
  pinMode(M_INPUT_2, OUTPUT);
  pinMode(M_INPUT_3, OUTPUT);
  pinMode(M_INPUT_4, OUTPUT);
  pinMode(M_ENABLE_A, OUTPUT);
  pinMode(M_ENABLE_B, OUTPUT);

  // Los inicia apagados
  digitalWrite(M_INPUT_1, LOW);
  digitalWrite(M_INPUT_2, LOW);
  digitalWrite(M_INPUT_3, LOW);
  digitalWrite(M_INPUT_4, LOW);
  digitalWrite(M_ENABLE_A, LOW);
  digitalWrite(M_ENABLE_B, LOW);
}

void motor_der(int velocidad) {
  if(velocidad > 0) {// Hacia delante
    digitalWrite(M_INPUT_2, LOW);// Direccion de giro
    digitalWrite(M_INPUT_1, HIGH);

    analogWrite(M_ENABLE_A, velocidad);// Velocidad (siempre un parametro positivo para PWM)

  }
  else if(velocidad < 0) {// Hacia atras
    digitalWrite(M_INPUT_2, HIGH);// Direccion de giro
    digitalWrite(M_INPUT_1, LOW);

    analogWrite(M_ENABLE_A, -velocidad);// Velocidad (siempre un parametro positivo para PWM)

  }
  else {//Parado
    digitalWrite(M_ENABLE_A, LOW);// Motor apagado
  }
}

void motor_izq(int velocidad) {
  if(velocidad > 0) {// Hacia delante
    digitalWrite(M_INPUT_4, LOW);// Direccion de giro
    digitalWrite(M_INPUT_3, HIGH);

    analogWrite(M_ENABLE_B, velocidad);// Velocidad (siempre un parametro positivo para PWM)

  }
  else if(velocidad < 0) {//Hacia atras
    digitalWrite(M_INPUT_4, HIGH);// Direccion de giro
    digitalWrite(M_INPUT_3, LOW);

    analogWrite(M_ENABLE_B, -velocidad);// Velocidad (siempre un parametro positivo para PWM)

  }
  else {//Parado
    digitalWrite(M_ENABLE_B, LOW);// Motor apagado
  }
}

/*******************************************/
int comprobarValoresEnRango(int *array,int num,int min, int max){
  int j;
  int contador=0;
  for(j=0;j<num;j++){
    if(array[j]<max && array[j]>min)
      contador++;
  }
  return contador;
}

/********** MUX ****************/
void configuraPinesMUX() {
  int j;
  pinMode(MUX_S0, OUTPUT);
  pinMode(MUX_S1, OUTPUT);
  pinMode(MUX_S2, OUTPUT);
  for(j=0;j<4;j++){
    minIRSensor[j]=2000;
    maxIRSensor[j]=-1;
  }
  for(j=4;j<8;j++){
    minLDRSensor[j-4]=2000;
    maxLDRSensor[j-4]=-1;
  }
}

int leePinMuxAnalogico(int pinID) {
  switch(pinID){
    case 0:
      digitalWrite( MUX_S0,0);
      digitalWrite( MUX_S1,0);
      digitalWrite( MUX_S2,0);
      break;
      case 1:
      digitalWrite( MUX_S0, 1 );
      digitalWrite( MUX_S1,0 );
      digitalWrite( MUX_S2, 0 );
      break;
     case 2:
      digitalWrite( MUX_S0, 0 );
      digitalWrite( MUX_S1,1 );
      digitalWrite( MUX_S2, 0 );
      break;
     case 3:
      digitalWrite( MUX_S0, 1 );
      digitalWrite( MUX_S1,1 );
      digitalWrite( MUX_S2, 0 );
      break;
     case 4:
      digitalWrite( MUX_S0, 0 );
      digitalWrite( MUX_S1,0 );
      digitalWrite( MUX_S2, 1 );
      break;
     case 5:
      digitalWrite( MUX_S0, 1 );
      digitalWrite( MUX_S1,0 );
      digitalWrite( MUX_S2, 1 );
      break;
     case 6:
      digitalWrite( MUX_S0, 0 );
      digitalWrite( MUX_S1,1);
      digitalWrite( MUX_S2, 1 );
      break;
     case 7:
      digitalWrite( MUX_S0,1);
      digitalWrite( MUX_S1,1);
      digitalWrite( MUX_S2,1);
      break;
     default:
      break;

  }
  /*digitalWrite( MUX_S0, bitRead(pinID,0) ); // Configuramos los pines de selección
  digitalWrite( MUX_S1, bitRead(pinID,1) );
  digitalWrite( MUX_S2, bitRead(pinID,2) );*/
  delayMicroseconds(2); // Esto no debería ser necesario ya que el MUX reacciona en <500ns
  return analogRead(MUX_Z);

}
int readPinMuxIRCalibrated(int pinID){
  int lectura;
  lectura=1023-leePinMuxAnalogico(pinID);


  if(lectura>maxIRSensor[pinID]){
    return 1000;
  }
  else if(lectura<minIRSensor[pinID]){
    return 0;
  }
  else{
    int valor = map(lectura,minIRSensor[pinID],maxIRSensor[pinID],0,1000);
    //int valor=( (lectura-minIRSensor[pinID])/(maxIRSensor[pinID]-minIRSensor[pinID]) )*1000;
    return valor;
  }
}
int errorLinePasado;
int readLineCNY70(){
  int j;
  int suma=0;
  int lectura;
  long errorLine=0;
  long errorLineCero=0;
  int linea=0;
  lectura=readPinMuxIRCalibrated(IR_1);
  //Serial.print("IR1: ");Serial.print(lectura);Serial.print("  \n");
  if(lectura>350){
    linea=1;
  }
  if(lectura>50){
    suma+=lectura;
  }
   lectura=readPinMuxIRCalibrated(IR_2);
 //  Serial.print("IR2: ");Serial.print(lectura);Serial.print("  \n");
  if(lectura>350){
    linea=1;
  }
  if(lectura>50){
    suma+=lectura;
    errorLine+=(1000*(long)lectura);
  }
  lectura=readPinMuxIRCalibrated(IR_3);
 // Serial.print("IR3: ");Serial.print(lectura);Serial.print("  \n");
  if(lectura>350){
    linea=1;
  }
  if(lectura>50){
    suma+=lectura;
    errorLine+=(2000*(long)lectura);
  }
  lectura=readPinMuxIRCalibrated(IR_4);
  //Serial.print("IR4: ");Serial.print(lectura);Serial.print("  \n");
  if(lectura>350){
    linea=1;
  }
  if(lectura>50){
    suma+=lectura;
    errorLine+=(3000*(long)lectura);
  }
  /*Serial.print("  ERROR1:  ");
  Serial.print(errorLine);*/
  errorLine/=suma;
  /*Serial.print("  Suma:  ");
  Serial.print(suma);
  Serial.print("  ERROR1:  ");
  Serial.print(errorLine);*/
  errorLineCero=errorLine-1500;
  /*Serial.print("  ERROR-Cero:  ");
  Serial.print(errorLineCero);
  Serial.println("  ");*/
  if(!linea && errorLinePasado<=0){
    errorLinePasado=-1500;
    return -1500;
  }
  else if(!linea && errorLinePasado>0){
    errorLinePasado=1500;
    return 1500;
  }
  else{
    errorLinePasado=errorLineCero;
    return errorLineCero;
  }

}

int leePinMuxDigital(int pinID) {

  digitalWrite( MUX_S0, bitRead(pinID,0) ); // Configuramos los pines de selección
  digitalWrite( MUX_S1, bitRead(pinID,1) );
  digitalWrite( MUX_S2, bitRead(pinID,2) );
  delayMicroseconds(1); // Esto no debería ser necesario ya que el MUX reacciona en <500ns
  return digitalRead(MUX_Z);

}

void sensorMuxIRCalibrar(){
  int lectura;
  lectura=1023-leePinMuxAnalogico(IR_1);
  if(lectura<minIRSensor[IR_1])
    minIRSensor[IR_1]=lectura;
  if(lectura>maxIRSensor[IR_1])
    maxIRSensor[IR_1]=lectura;
  lectura=1023-leePinMuxAnalogico(IR_2);
  if(lectura<minIRSensor[IR_2])
    minIRSensor[IR_2]=lectura;
  if(lectura>maxIRSensor[IR_2])
    maxIRSensor[IR_2]=lectura;
  lectura=1023-leePinMuxAnalogico(IR_3);
  if(lectura<minIRSensor[IR_3])
    minIRSensor[IR_3]=lectura;
  if(lectura>maxIRSensor[IR_3])
    maxIRSensor[IR_3]=lectura;
  lectura=1023-leePinMuxAnalogico(IR_4);
  if(lectura<minIRSensor[IR_4])
    minIRSensor[IR_4]=lectura;
  if(lectura>maxIRSensor[IR_4])
    maxIRSensor[IR_4]=lectura;
}

void sensorMuxLDRCalibrar(){
  int lectura;
  int j;
  for(j=0;j<4;j++){
    lectura=leePinMuxAnalogico(j+4);
    if(lectura<minLDRSensor[j])
      minLDRSensor[j]=lectura;
    if(lectura>maxLDRSensor[j])
      maxLDRSensor[j]=lectura;
  }

}

int readPinMuxLDRCalibrated(int pinID){

 int lectura;
  lectura=leePinMuxAnalogico(pinID+4);
  if(lectura>maxLDRSensor[pinID]){
    maxLDRSensor[pinID]=lectura;
    return 1000;
  }
  else if(lectura<minLDRSensor[pinID]){
    minLDRSensor[pinID]=lectura;
    return 0;
  }
  else{
    return map(lectura,minLDRSensor[pinID],maxLDRSensor[pinID],0,1000);
  }
}



/********* PLACA SENSORES QTR-8RC **********/
QTRSensorsRC qtrrc((unsigned char[]) {
  QTR_0, QTR_1, QTR_2, QTR_3, QTR_4, QTR_5, QTR_6, QTR_7}
, NUM_SENSORS, TIMEOUT, EMITTER_PIN);



void calibraIR(int seg){
  int i;
  delay(500);
  digitalWrite(LED,HIGH);
  for (i = 0; i < 40*seg; i++)
  {
    qtrrc.calibrate();       // reads all sensors 10 times at 2500 us per read (i.e. ~25 ms per call)
  }
  digitalWrite(LED,LOW);


  //Muestro los valores de calibracion por el puerto seria

  Serial.println("Resultados\nMinimos:");
  for (i = 0; i < NUM_SENSORS; i++)
  {
    Serial.print(qtrrc.calibratedMinimumOn[i]);
    Serial.print(" ");
  }
  Serial.println();

  Serial.println("Maxmos:");
  for (i = 0; i < NUM_SENSORS; i++)
  {
    Serial.print(qtrrc.calibratedMaximumOn[i]);
    Serial.print(" ");
  }
  Serial.println();
  Serial.println();
  delay(1000);
}

void pruebaSensoresIR(unsigned int *sensorValues){
  unsigned int position = qtrrc.readLine(sensorValues);

  //qtrrc.read(sensorValues);


  unsigned char i;
  for (i = 0; i < NUM_SENSORS; i++)
  {
    Serial.print(sensorValues[i]*10/1001);
    Serial.print(' ');
  }
  Serial.print("    ");
  Serial.println(position);

  delay(250);
}


/**PID**/
int lastError=0;
unsigned long lastTime=0;
int Derror=0;
int getErrorPD(unsigned int *sensorValues,double kp, double kd){
  unsigned long currentTime;
  unsigned int position = qtrrc.readLine(sensorValues);
  int error=position-(NUM_SENSORS-1)*500; //Centrar el error en el 0
  errArray[i]=error;
  currentTime=micros();

  if(currentTime-lastTime > INTER_ERR_D){//Genero el error derivativo
    Derror=kd*(error-lastError)/(currentTime-lastTime);
    lastTime=currentTime;
    lastError=error;
  }

  /*Si el error ha cambiado mucho en proporcion aunque no haya pasado suficiente tiempo actualizo la parte derivativa
   if( (error/lastError)>2 || (error/lasError)<-2){
   Derror=kd*(error-lastError)/(currentTime-lastTime);
   lastTime=currentTime;
   lastError=error;
   }
   */
  return kp*error+Derror;
}
/*^^^^^^^^^^^^^^^^^^^^^^^^^^^^^^^^^^^^^^^^^^^^^^^^^^^^*/
double kProp=KP;
double kDer=KD;


void setup(){ //11,5 seg
  int j,pulsador;
  double mod;
  Serial.begin(19200);
  delay(3000);
  pinMode(PULSADOR,OUTPUT);
  Serial.println("STARTUP");
  unsigned long time=0;
  pinMode(LED, OUTPUT);
  for(j=0;j<200;j++)
    errArray[j]=9000;//INICIALIZO EL ERROR DE ARRAY A UN VALOR: "NO RECTA"

  Serial.println("Configurando pines MUX");
  configuraPinesMUX();
  Serial.println("Configurando driver motores");
  inicia_pines_driver_motores();



  delay(1000);
  Serial.println("Calibrando CNY70...");
  delay(10);

  //2 - calibracion CNY70

  //while( (pulsador=digitalRead(PULSADOR))==1 && (micros()-time)<250000);
  //if(pulsador==1){
    digitalWrite(LED,HIGH);
    for(j=0;j<2500;j++){  //5 seg
      sensorMuxIRCalibrar();
      delay(2);
    }
    for(j=0;j<4;j++){
      EEPROM.write(j+10,minIRSensor[j]/4);
      EEPROM.write(j+20,maxIRSensor[j]/4);
      Serial.print(j);
      Serial.print(" ");
      Serial.print(minIRSensor[j]/4);
      Serial.print(" ");
      Serial.println(maxIRSensor[j]/4);

    }
    digitalWrite(LED,LOW);
  /*}else{
    for(j=0;j<NUM_SENSORS;j++){
      minIRSensor[j]=EEPROM.read(j+10)*4;
      maxIRSensor[j]=EEPROM.read(j+20)*4;
    }
  }*/
  Serial.println("CALIBRANDO IR Delanteros");
  calibraIR(5);
  Serial.println("CALIBRACION COMPLETADA. Iniciando Programa...");
  delay(10);

  digitalWrite(LED,HIGH);
  delay(250);
  digitalWrite(LED,LOW);
  delay(250);
  digitalWrite(LED,HIGH);
  delay(250);
  digitalWrite(LED,LOW);

  pinMode(PULSADOR,OUTPUT);
  Serial.println("TS\tErrD\tErrT\tAng\tVm1\tVm2");


  //LANZADOR DEL LOOP
  //pinMode(PULSADOR,INPUT);
  //while(digitalRead(PULSADOR)==1);
  //while(digitalRead(PULSADOR)==0);






  initialTime = millis();
  lastLogTime = initialTime;
  pinMode(PULSADOR,INPUT);

}

void loop() {
  // put your main code here, to run repeatedly:
  //pruebaSensoresIR(sensorValues);
  //delay(200);


  int m1Speed;
  int m2Speed;
  int err;


  err=getErrorPD(sensorValues,kProp, kDer); //[-280,280]

  m1Speed = VEL_BASE + err;
  m2Speed = VEL_BASE - err;

  motor_der(m1Speed);
  motor_izq(m2Speed);
}

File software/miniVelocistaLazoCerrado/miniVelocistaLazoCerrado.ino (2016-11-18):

#include <Arduino.h>
//#include <EnableInterrupt.h>
#include "Vector9000.h"

#define PIN_BOTON 7

#define speed2ticks(a) ( (a*600) / (31.1*3.1415) ) //speed in m/s 
#define ticks2speed(a) ( (a/600) * (31.1*3.1415) )

#define DIFF_ENCODERS_RECT 13
#define TIME_MAX_IN_RECTA 600 //tiempo máximo que está el robot en recta antes de frena. En ms.
#define TIME_MAX_FRENADA 30 //tiempo maximo de duracion de frenada tras recta
#define TIME_MAX_PUENTE 100 //tiempo maximo de duracion de frenada tras recta
#define TICK_ENC_MAX_RECTA 500 //ticks máximos que dura la recta antes de frenar. 50ticks por vuelta de rueda.
#define TICK_ENC_MAX_FRENADA 100 //ticks máximos que dura la frenada

#define INTERVAL_RECT_TASK 100
#define MIN_VEL_EN_RECTA 10

/*int VEL_BASE_PUENTE=speed2ticks(1);
int VEL_BASE_RECTA=speed2ticks(1);
int VEL_BASE_CURVA=speed2ticks(1);
int VEL_BASE_FRENO=speed2ticks(1);
int VEL_BASE= speed2ticks(1);*/
//Vector9000 robot = Vector9000(0.047/20.0,4050.283/20.0,0);//(kp,kd, ki);
//Vector9000 robot = Vector9000(0.0012,150,0);
Vector9000 robot = Vector9000(0.0491,2950.283,0);//(kp,kd, ki);
int VEL_BASE_PUENTE=0;
int VEL_BASE_RECTA=102;//120
int VEL_BASE_CURVA=102;//110
int VEL_BASE_FRENO=-45;
int VEL_BASE=45;//105;

boolean schedulerVELBASEOn=false;
unsigned long nextTaskTime=4967295;
unsigned long nextEndDerTaskCount=4294967295;
unsigned long nextEndIzqTaskCount=4294967295;
void (*callback)(void);


boolean enRecta=false;
unsigned long nextCheckRectTask=0;
 long lastEncDer=0;
 long lastEncIzq=0;

#include "speedController.h"
/**
 * Control variables
 */
 extern int targetSpeedL;
 extern int targetSpeedR;

/**
 * Output variable. To be readed
 */
 extern long encoderCount;
 extern float curSpeedL;
 extern float curSpeedR;
 extern float accX;
 extern float decX;


/**
 * Tune variables
 */
// extern float ir_weight;
// extern float kpX, kdX;
// extern float kpW, kdW;//used in straight
// extern float kpW0, kdW0;//used in straight
// extern float kpWir, kdWir;//used with IR errors

void printTelemetria(float err){
    Serial.print("pT ");
    Serial.print(micros()/1000000.0);
    Serial.print("/");
    Serial.print(err);
    Serial.print("|");
    Serial.print(robot.readLine());
    Serial.print("|");
    Serial.print(robot._kp*1000);
    Serial.print(" ");
    Serial.print(robot._kd);
    Serial.print(" ");
    Serial.println(robot._ki);
}

bool boton_pulsado() {
  return !digitalRead(PIN_BOTON);
}

//volatile unsigned long cuentaEncoderIzquierdo = 0; 
//volatile unsigned long cuentaEncoderDerecho = 0;

volatile long count_enc_r;
volatile long count_enc_l;

void aumentarCuentaIzquierda()
{
  //cuentaEncoderIzquierdo++;
  static int8_t lookup_table[] = {0,0,0,-1,0,0,1,0,0,1,0,0,-1,0,0,0};
  static uint8_t enc2_val = 0;

    uint8_t v = (digitalRead(A0)<<1) | digitalRead(2);
    enc2_val = enc2_val << 2;
    enc2_val = enc2_val | (v & 0b11);

  count_enc_l = count_enc_l + lookup_table[enc2_val & 0b1111];

}

void aumentarCuentaDerecha()
{
  //cuentaEncoderDerecho++;


   static int8_t lookup_table[] = {0,0,0,-1,0,0,1,0,0,1,0,0,-1,0,0,0};
   static uint8_t enc1_val = 0;

   uint8_t v = (digitalRead(4)<<1) | digitalRead(3);
   enc1_val = enc1_val << 2;
   enc1_val = enc1_val | (v & 0b11);

   count_enc_r = count_enc_r - lookup_table[enc1_val & 0b1111];
}

void setup(){
    robot.config();
    Serial.begin(19200);
    pinMode(PIN_BOTON, INPUT_PULLUP);
    delay(20);
    
    robot.calibrateIR( 5, true );
    long millisini = millis();
    while(!boton_pulsado()){
      delay(10);
      if (millis() > millisini + 5000){
        robot.ledOn();
          VEL_BASE_PUENTE=speed2ticks(0.9);
         VEL_BASE_RECTA=speed2ticks(0.9);
         VEL_BASE_CURVA=speed2ticks(0.9);
         VEL_BASE_FRENO=speed2ticks(0.9);
         VEL_BASE= speed2ticks(0.93);
      }
    }
    while(boton_pulsado()) delay(10);
    
    attachInterrupt(digitalPinToInterrupt(Vector9000::ENC_DER_PIN), aumentarCuentaDerecha, CHANGE); 
    attachInterrupt(digitalPinToInterrupt(Vector9000::ENC_IZQ_PIN), aumentarCuentaIzquierda, CHANGE);

    delay(4960);
    resetSpeedProfile();
}



void inline activarCurvas(){
  VEL_BASE=VEL_BASE_CURVA;
  robot.config();
}
unsigned long contRecta=0;
void inline activarFreno(){
  enRecta=false;
  unsigned int longRecta= contRecta*1;
  if(longRecta>30)longRecta=30;
  VEL_BASE=VEL_BASE_FRENO-longRecta;
  robot.config();
  //Configurar duracion de frenada
  schedulerVELBASEOn=true;
  callback=&activarCurvas;
  nextTaskTime=millis()+TIME_MAX_FRENADA;
  nextEndDerTaskCount=count_enc_r+TICK_ENC_MAX_FRENADA;
  nextEndIzqTaskCount=count_enc_l+TICK_ENC_MAX_FRENADA;
}

void inline activarRecta(){
  enRecta=true;
  VEL_BASE= VEL_BASE_RECTA;
  //Configurar el punto de frenada
  //schedulerVELBASEOn=true;
  //callback=&activarFreno;
  //nextTaskTime=millis()+TIME_MAX_IN_RECTA;
  //nextEndDerTaskCount=cuentaEncoderDerecho+TICK_ENC_MAX_RECTA;
  //nextEndIzqTaskCount=cuentaEncoderIzquierdo+TICK_ENC_MAX_RECTA;
}

void inline activarPuente(){
  enRecta=false;
  VEL_BASE=VEL_BASE_PUENTE;
  robot.config();
  //Configurar duracion de frenada
  schedulerVELBASEOn=true;
  callback=&activarCurvas;
  nextTaskTime=millis()+TIME_MAX_PUENTE;
}

double posX=0;
double posY=0;
double ang =0;
long last_count_enc_r=0;
long last_count_enc_l=0;
#define DIAMETRO 30.4
#define N_MOTOR  10.0
#define RES_ENC  6.0
#define LEN 165
float Cm = (float(3.1416 * DIAMETRO))/(float(N_MOTOR * RES_ENC));


void inline calcularPosOdometria(){
  long enc1 = count_enc_r - last_count_enc_r;
  last_count_enc_r=count_enc_r;
  long enc2 = count_enc_l - last_count_enc_l;
  last_count_enc_l=count_enc_l;
  float avance1 = (float(enc1))*Cm;
  float avance2 = (float(enc2))*Cm;
  float varPosC = (avance1+avance2)/2;
  ang +=  (avance1-avance2)/LEN;
  posX +=varPosC*cos(ang);
  posY +=varPosC*sin(ang);
}

unsigned long nextSpeedProfile = 0;
unsigned long nextMainPID = 0;
unsigned long nextSendPos =0;
unsigned long nextCalcPos=0;
void loop() {
    if(boton_pulsado()) {
      robot.setSpeed(0,0);
      delay(1000);
      setup();
      return;
    }
//    if(schedulerVELBASEOn && (millis()>nextTaskTime)) {// || cuentaEncoderDerecho>nextEndDerTaskCount || cuentaEncoderIzquierdo>nextEndIzqTaskCount) ){ //planificador por tiempo para acelerar/frenar en recta
//      schedulerVELBASEOn=false;
//      callback();
//    }
      /*if(millis() > nextMainPID){
        nextMainPID=millis()+30;
        double errDif = robot.getErrorLine();//PID(err);
        //Serial.println(errDif);
        //printTelemetria(errDif);
        curSpeedR = VEL_BASE + errDif;
        curSpeedL = VEL_BASE - errDif;
      }
    
    if(millis() > nextSpeedProfile){
      nextSpeedProfile=millis()+10;
      speedProfile(NULL);
    }*/

    double errDif = robot.getErrorLine();//PID(err);
    //printTelemetria(errDif);
    robot.setSpeed( VEL_BASE - errDif, VEL_BASE + errDif );
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

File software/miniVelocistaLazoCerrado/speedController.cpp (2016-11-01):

#if ARDUINO >= 100
 #include "Arduino.h"
#else
 #include "WProgram.h"
#endif

#include "speedController.h"

#include "Vector9000.h"

//public
/**
 * Control variables
 */
int targetSpeedL;
int targetSpeedR;

/**
 * Output variable. To be readed
 */
  long encoderCount;
  float curSpeedL;
  float curSpeedR;
  float accX;
  float decX;
  float accW;
  float decW;

/**
 * Tune variables
 */
  float ir_weight;
  float kpL, kdL;
  float kpR, kdR; //used in straight





//private
int encoderFeedbackX = 0;
int encoderFeedbackW = 0;
float pidInputL = 0;
float pidInputR = 0;
float posErrorL = 0;
float posErrorR = 0;
float oldPosErrorL = 0;
float oldPosErrorR = 0;

int posPwmL = 0;
int posPwmR = 0;



  
long encoderChange=0;
 long leftEncoderChange=0;
 long rightEncoderChange=0;
 long leftEncoderOld = 0;
 long rightEncoderOld = 0;
long leftEncoder = 0;
long  rightEncoder = 0;
long leftEncoderCount = 0;
long rightEncoderCount = 0;
    
int leftBaseSpeed = 0;
int rightBaseSpeed = 0;


void speedProfile(void *a){ 
    getEncoderStatus(); 
    updateCurrentSpeed(); 
    calculateMotorPwm(); 
}
 extern long count_enc_l; 
 extern long count_enc_r;

void getEncoderStatus()
{
     long leftEncoder = count_enc_l;//robot.getEncLeftCount(); //leftEncoder = TIM2->CNT;//read current encoder ticks from register of 32 bit general purpose timer 2
     long rightEncoder = count_enc_r;//robot.getEncRightCount(); //rightEncoder = TIM5->CNT;//read current encoder ticks from register of 32 bit general purpose timer 5

    leftEncoderChange = leftEncoder - leftEncoderOld;
    rightEncoderChange = rightEncoder - rightEncoderOld;

    leftEncoderOld = leftEncoder;
    rightEncoderOld = rightEncoder;

    leftEncoderCount += leftEncoderChange;
    rightEncoderCount += rightEncoderChange;
    encoderCount =  (leftEncoderCount+rightEncoderCount)/2;
}



void updateCurrentSpeed(void)
{
    if(curSpeedL < targetSpeedL && curSpeedL >= 0){
        curSpeedL += accX;
        if(curSpeedL > targetSpeedL)
            curSpeedL = targetSpeedL;
    }else if(curSpeedL > targetSpeedL && curSpeedL > 0){
        curSpeedL -= decX;
        if(curSpeedL < targetSpeedL)
            curSpeedL = targetSpeedL;
    }else if(curSpeedL < targetSpeedL && curSpeedL < 0){
        curSpeedL += decX;
        if(curSpeedL > targetSpeedL)
            curSpeedL = targetSpeedL;
    }else if(curSpeedL > targetSpeedL && targetSpeedL <= 0){
        curSpeedL -= accX;
        if(curSpeedL < targetSpeedL)
            curSpeedL = targetSpeedL;
    }
    
    if(curSpeedR < targetSpeedR && curSpeedR >= 0){
        curSpeedR += accX;
        if(curSpeedR > targetSpeedR)
            curSpeedR = targetSpeedR;
    }else if(curSpeedR > targetSpeedR && curSpeedR > 0){
        curSpeedR -= decX;
        if(curSpeedR < targetSpeedR)
            curSpeedR = targetSpeedR;
    }else if(curSpeedR < targetSpeedR && curSpeedR < 0){
        curSpeedR += decX;
        if(curSpeedR > targetSpeedR)
            curSpeedR = targetSpeedR;
    }else if(curSpeedR > targetSpeedR && targetSpeedR <= 0){
        curSpeedR -= accX;
        if(curSpeedR < targetSpeedR)
            curSpeedR = targetSpeedR;
    }
    
}


void calculateMotorPwm(void) // encoder PD controller
{

  
 
    posErrorL += curSpeedL - leftEncoderChange;
    posErrorR += curSpeedR - rightEncoderChange;
   
  

//    Serial.print("Time: ");
//    Serial.println(micros());
//    Serial.print("SppedL: ");
//    Serial.println(curSpeedL);
//    Serial.print("SppedR: ");
//    Serial.println(curSpeedR);
//    Serial.print("EncoderFedbackL: ");
//    Serial.print(leftEncoderChange);
//    Serial.print(" ");
//    Serial.print(rightEncoderChange);

      posPwmL = kpL * posErrorL + kdL * (posErrorL - oldPosErrorL);
      posPwmR = kpR * posErrorR + kdR * (posErrorR - oldPosErrorR);

//     Serial.print(" ");
//    Serial.print((1.0*posPwmL)/10.0);
//    Serial.print(" ");
//    Serial.println((1.0*posPwmR)/10.0);

//    Serial.print("OutputSpeedL");
//    Serial.println(posPwmL);
//    Serial.print("OutputSpeedR");
//    Serial.println(posPwmR);

    oldPosErrorL = posErrorL;
    oldPosErrorR = posErrorR;

    robot.setSpeed(posPwmL,posPwmR);
    
//    if(p_telemetria<SIZE_TELEMETRIA){
//      telemetria[p_telemetria][0]=micros();
//      telemetria[p_telemetria][1]=curSpeedL;
//      telemetria[p_telemetria][2]=encoderFeedbackX;
//      //telemetria[p_telemetria][3]=curSpeedR;
//      telemetria[p_telemetria][3]=curSpeedR;
//      telemetria[p_telemetria][4]=rotationalFeedback;
//      telemetria[p_telemetria][5]=posErrorWir;
//      //telemetria[p_telemetria][6]=leftEncoderChange;
//      p_telemetria++;
//    }
    
}





void resetSpeedProfile(void)
{
    //reset Everything and reTune parameters;


    robot.setSpeed(0,0);//setLeftPwm(0);//setRightPwm(0);

  //Tune parameters
   ir_weight = 0.0;
   kpL = 0.5; kdL = 7;
   kpR = 0.5; kdR = 7;
  

   accX = 0.5;// 2ticks * 100s^-1 * (30mm * pi)/(100 ticks / rev) = 188.49 mm/s^2  [ejecutando la rutina cada 10ms]
   decX = 0.5; // -282.74 mm/s^

   


//reset variables
    
    curSpeedL = 0;
    curSpeedR = 0;
    targetSpeedL = 0;
    targetSpeedR = 0;
    posErrorL = 0;
    posErrorR = 0;
    oldPosErrorL = 0;
    oldPosErrorR = 0;
    leftEncoderOld = 0;
    rightEncoderOld = 0;
    leftEncoder = 0;
    rightEncoder = 0;
    leftEncoderCount = 0;
    rightEncoderCount = 0;
    encoderCount = 0;
    leftBaseSpeed = 0;
    rightBaseSpeed = 0;

    //robot.resetEncoders();//reset left encoder count //TIM5->CNT = 0;//reset right encoder count
    count_enc_l=0; 
    count_enc_r=0;
}

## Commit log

2016-02-19 Añadidos los ficheros originales
    [Chasis.scad, Chasis.stl, CubiertaCarcasa.scad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]
2016-02-20 Movida pieza a la carpeta de diseño 3D
    [LineSensorV2_new.scad]
2016-02-25 ajuste de PID con algoritmo PSO
2016-03-28 Añadidos documentos de cosmobot 2013, y realizado backup de la librería QTR
2016-03-29 comparación velocista EDU
    [Chasis.scad, base_velocistaEdu_fixed.stl]
2016-03-29 change translate
    [Chasis.scad]
2016-03-29 Actualizado el chasis incorporando las sugerencias de Victor: chasis mas fino, largo, con ruedas traseras mas separadas y soporte para la batería
    [Chasis.scad, Chasis_v2.stl, LineSensorV2_new.scad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]
2016-03-30 mas huecos
    [Chasis.scad]
2016-04-03 codigo velocista con encoders
2016-04-03 Aligerado el chasis, y generado chasis mas corto, para rastreadores
    [Chasis.stl, Chasis_corto.scad, Chasis_corto.stl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]
2016-04-03 Movidos STL a su propia carpeta, restaurado el stl de la v1
    [Chasis_v1.stl, Chasis_v2.stl, Chasis_v2_corto.scad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]
2016-04-03 rastreado codificado v0.0\n TODO: incluir aseguracion de que la senal leida no es un error volviendo a leer pasado cierto tiempo
    [Vector9000.cpp, robolidRastreador.ino]
2016-04-04 Aumentada tolerancia sensor QTR8
    [Chasis_v2.stl, Chasis_v2_corto.scad, Chasis_v2_corto.stl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]
2016-04-04 Añadido scad para las ruedas
    [rueda.scad]
2016-04-04 fixed errors in robot.readPosLineWithSignals( &sig );
    [Vector9000.cpp, robolidRastreador.ino]
2016-04-04 reorganizado el codigo con funciones privadas para evitar la redundancia y corregir errores mas facil, corregidos errores en las funciones de bifurcacion
    [Vector9000.cpp]
2016-04-05 Prueba con encoders
2016-04-05 mejoraras del CRM, robot bastante funcional\nAniadido codigo para deterctar si la linea se pierde por los lados (habiendo otra linea) en las bifurcaciones (lineas 350:359 Vector9000.cpp) Falta probar.
2016-04-05 incrementa los errores con el tiempo cuando se pierde la liena de los sensores
    [Vector9000.cpp]
2016-04-06 Reducida velocidad, cambiados pines, incorporado boton
2016-04-06 Bugfixes varios. Lo básico ya funciona
    [Vector9000.cpp, robolidVelocista.ino]
2016-04-06 pruebas nocturnas, no tiene mala pinta, pero se reinicia la placa sin motivo aparente
2016-04-07 mejor hasta la fecha
2016-04-07 Lento pero parece que responde bastante bien.. quizas se pdria subir un poco las velocidaddes en las lineas..
2016-04-07 Modificada rueda
    [rueda.scad]
2016-04-07 Añadidas fotos de los dos robots
2016-04-08 velocista robolid, mas o menos rapido. base
2016-04-09 datos telemetria velocistas robolid 2016
2016-04-25 Añadidas imágenes de Robolid 2016
2016-10-28 codigo de velocista para Vector9000 con controlador de velocidad como el micromouse
2016-10-30 codigo con lazo cerrado para controlar los motores con la velocidad real proporcionada por los encoders
2016-10-30 velocista grande con lazo cerrado para cada uno de los motores (encoders opticos 10ticks por vuelta)
2016-11-01 lazo cerrado para el velocista pequeño con encoders magneticos y medicion de ticks negativos
2016-11-01 Velocista funcionando con velocidades reales en metros por segundo
2016-11-01 Telemetria miniVector9000 de posicion formato: <tiempo(ms)> <enc1> <enc2>
2016-11-03 animacion grafica de la posicion de robot obtenida de los ficheros con las medidas de los encoders
2016-11-06 Codigo Velocista Vector9000, ganador en la oshwdem2016
2016-11-06 Código velocista MiniVector9000 en la oshwdem2016
2016-11-18 codigo con ecuaciones de odometria calculadas cada 20ms, hay algun error en el calculo del angulo, ver mas adelante
    [miniVelocistaLazoCerrado.ino]
